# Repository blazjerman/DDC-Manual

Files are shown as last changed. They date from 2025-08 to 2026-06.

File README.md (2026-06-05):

# DDC Manual – Project Overview

A web-based manual and documentation page for my **Discrete Digital Clock (DDC)** project.

**Live Manual:** [blazjerman.github.io/DDC-Manual](https://blazjerman.github.io/DDC-Manual/)

---

## About This Page

This page serves as the official manual and visual guide for the DDC — a custom-built discrete digital clock. The DDC Manual provides technical details, images, and schematics related to the project.

Here you can:
- Learn about the DDC’s design and functionality.
- Explore internal schematics and how the circuit is wired.
- View photos of the final physical build.
- Understand the layout and structure of the renderer.
- Use the manual as a reference for your own builds or modifications.

---

## Repository Contents

This GitHub repository includes everything shown on the manual website:

- `/index.html` – The main landing page of the DDC Manual.
- `/files/` – Contains useful documentation and project files like:
  - `DDC_Schematic.pdf` – The complete schematic of the clock.
  - `DDC.3mf` – 3D file of clock.
- `/images/` – Contains pictures and renderings of the DDC project:
  - Photos of the assembled clock.
  - PCB layout screenshots.
  - 3D model renders of the design.

---

## Preview

Here’s a quick look at the 3D render of the DDC design:

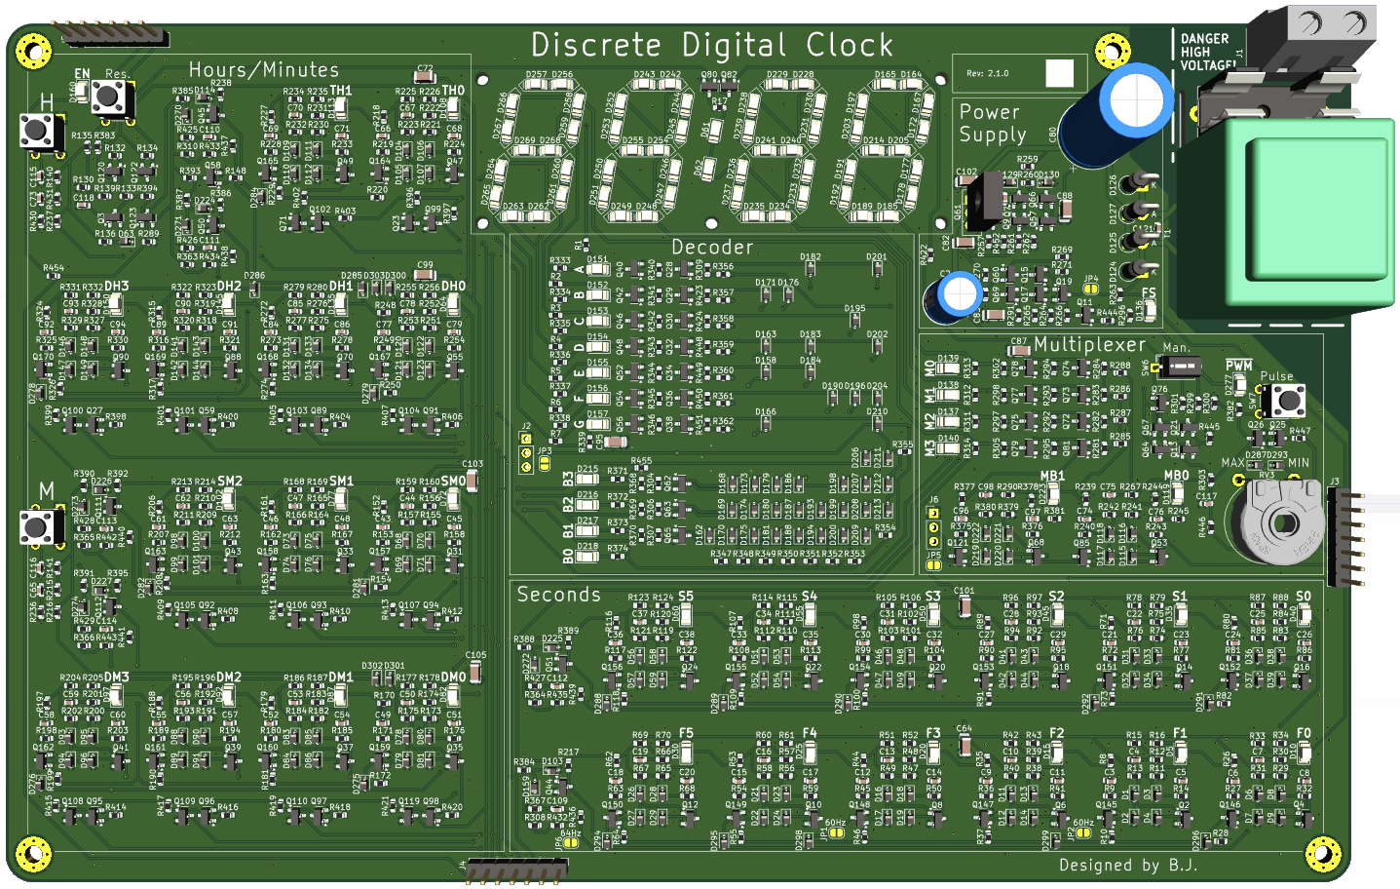
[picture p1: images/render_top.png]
DDC Render


> *Render of DDC*

---

## License

**DDC (Discrete Digital Clock) © 2025 Blaž Jerman**  
Licensed under [Creative Commons Attribution-NonCommercial 4.0 International (CC BY-NC 4.0)](https://creativecommons.org/licenses/by-nc/4.0/)

---

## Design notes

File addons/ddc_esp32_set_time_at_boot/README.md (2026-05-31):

# ESP32 WiFi Clock Setter

This ESP32 add-on sets the clock automatically when the clock boots.

On startup, the ESP32 connects to WiFi, gets the current time from NTP, turns WiFi off, and then uses the clock's J5 header to start and set the external clock.

## Installation

1. Install ESP32 board support in Arduino IDE:
   - Open **File -> Preferences**
   - Add this URL to **Additional Boards Manager URLs**:

     ```text
     https://raw.githubusercontent.com/espressif/arduino-esp32/gh-pages/package_esp32_index.json
     ```

   - Open **Tools -> Board -> Boards Manager**
   - Search for **esp32**
   - Install **esp32 by Espressif Systems**

2. Open the project file:

  ```text
  DDC-Manual/addons/ddc_esp32_set_time_at_boot/ddc_esp32_set_time_at_boot.ino
  ```

3. Set frequency:
  
  ```text
  Tools -> CPU Frequency -> 80MHz
  Tools -> Flash Frequency -> 40MHz
  ```

## ESP32 pins

| ESP32 pin | Use |
|---|---|
| GPIO 32 | Clock reset sense + clock start output |
| GPIO 27 | Set minutes output |
| GPIO 26 | Set hours output |
| GPIO 33 | WiFi reset button |
| GND | Common ground |

## Clock header J5

| J5 pin | Function | Connection |
|---|---|---|
| Pin 1 | Reset | Not used |
| Pin 2 | Boot reset check / start | ESP32 GPIO 32 |
| Pin 3 | 5V power | 5V supply only if safe |
| Pin 4 | Carry bit for day | Not used |
| Pin 5 | Set minutes | NPN transistor collector |
| Pin 6 | Set hours | NPN transistor collector |
| Pin 7 | Ground | ESP32 GND |

## Important power note

Do **not** power the ESP32 from USB and also connect another 5V supply to the ESP32 5V pin at the same time.

## J5 Pin 2 reset/start wire

Connect:

```text
J5 Pin 2 -> ESP32 GPIO 32
```

Behavior:

```text
Below 0.7V = clock reset/off
Above 0.7V = clock running
```

GPIO 32 is normally an analog input. At exact second `00`, ESP32 changes GPIO 32 to output HIGH to start the clock, then returns it to input mode.

## Minute and hour setting transistors

The hour and minute set pins are pulled up to **5V** on the clock board. The clock increments when these pins are pulled **LOW**, so they must be driven through an NPN transistor or another suitable level-shifting circuit. Do **not** connect these pins directly to the ESP32.

### Minutes

```text
ESP32 GPIO 27 -> 100k resistor -> NPN base
NPN emitter  -> GND
NPN collector -> J5 Pin 5
```

### Hours

```text
ESP32 GPIO 26 -> 100k resistor -> NPN base
NPN emitter  -> GND
NPN collector -> J5 Pin 6
```

Suitable NPN transistors:

```text
2N3904, BC547, 2N2222
```

## WiFi reset button

Connect:

```text
ESP32 GPIO 33 -> button -> GND
```

Hold the button while powering/resetting the ESP32. Keep holding for 3 seconds to clear saved WiFi and timezone.

## First WiFi setup

When no WiFi is saved, ESP32 creates:

```text
ESP32-WiFi-Setup
```

Connect to it and open:

```text
http://192.168.4.1
```

Enter WiFi SSID, password, and timezone. ESP32 saves them and restarts. You can check serial (bound rate 115200) for debugging.

## Startup sequence

1. ESP32 connects to saved WiFi.
2. It retries until WiFi works.
3. It retries NTP until time is known.
4. It turns WiFi off.
5. It checks GPIO 32 voltage.
6. If clock is reset/off, it waits for second `00`.
7. At exact `00`, GPIO 32 goes HIGH.
8. It pulses hours and minutes.
9. GPIO 32 returns to input mode.

## Troubleshooting

If WiFi setup opens every boot, check Serial Monitor (bound rate 115200) and GPIO 33 reset button wiring.
If hours/minutes do not increment, check NPN transistor wiring and common ground.

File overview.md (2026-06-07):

---
layout: page
title: Overview
permalink: /overview/
---

This section provides a simple explanation of how the clock operates. It is recommended for users who already have a basic understanding of electronics and some knowledge of transistors.

The clock includes many LED indicators to show how the system works (details about LED functions are provided below). The indicator LEDs operate at low current to increase their lifespan most run at 2 mA, except for the display LEDs, which are driven at around 15 mA due to multiplexing and their lower brightness.

All other components on the board are high quality. All ceramic capacitors are C0G type from Murata Electronics, and the transistors and diodes are sourced from ON Semiconductor.

The clock board is divided into different chambers, each labeled by name and representing a specific functional section. There are five labeled chambers:

- Power Supply  
- Seconds  
- Hours / Minutes  
- Decoder  
- Multiplexer  

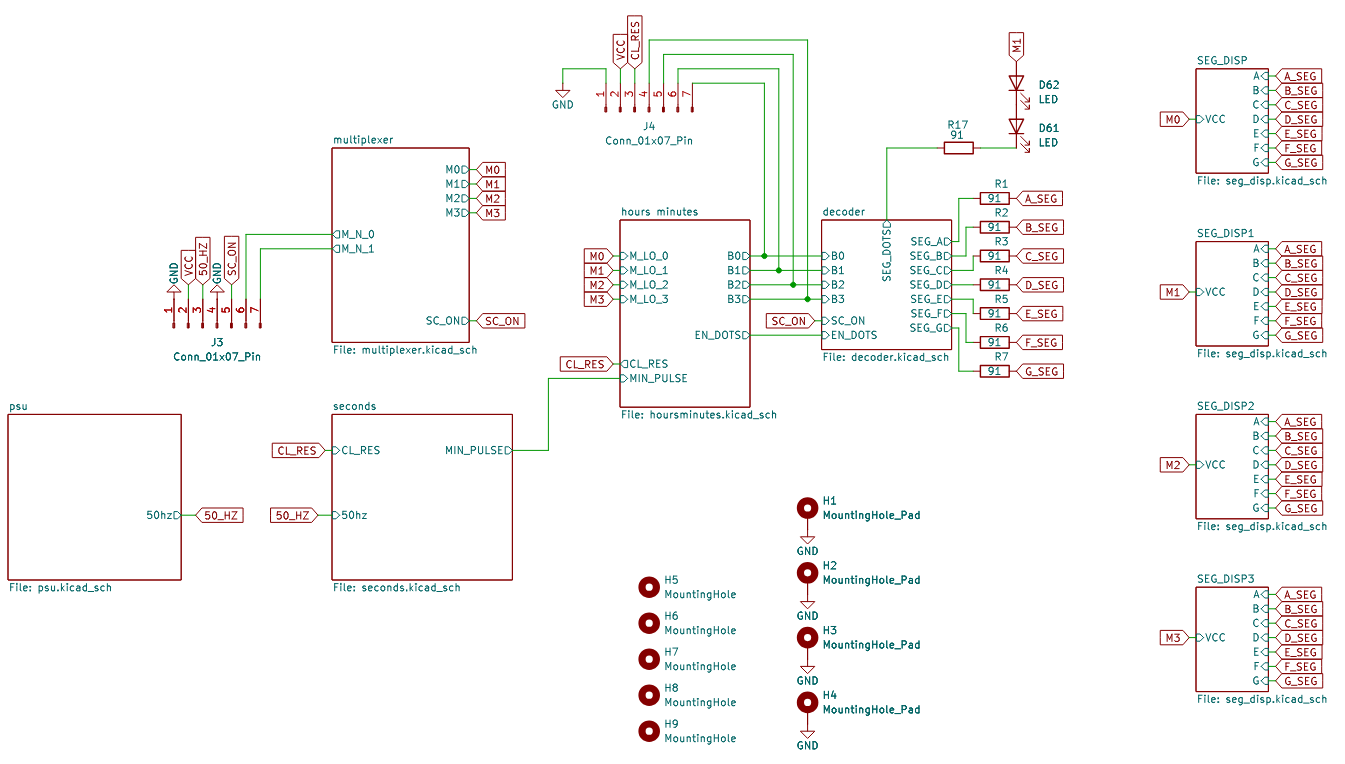
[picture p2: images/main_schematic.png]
Main schematic


You can find the full schematic of the clock here:  
[📄 View Clock Schematic (PDF)](/files/scheme.pdf)

Below is a simple description of each chamber.

### Power Supply

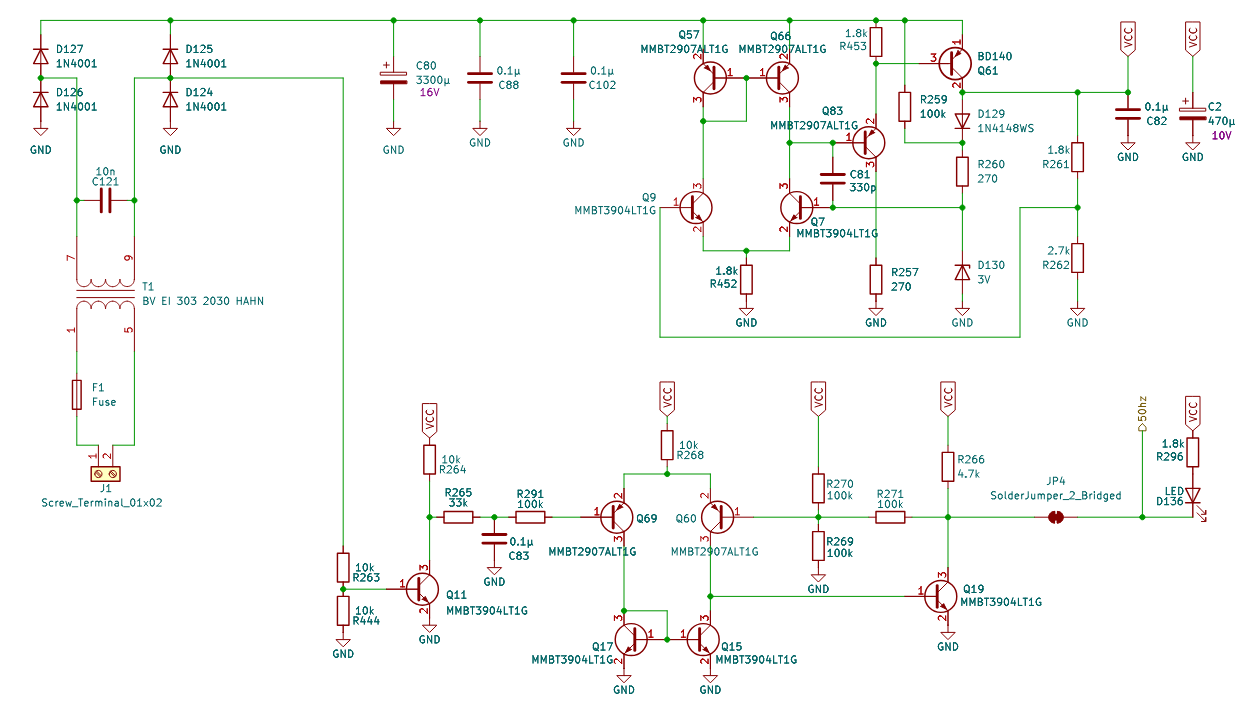
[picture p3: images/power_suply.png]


The power supply takes mains AC and converts it to a lower 6V using a transformer. A fuse is included on the primary side for safety. If a socket transformer is used, you should install a 1A fuse and short transformer pins 1 to 7 and 5 to 9. This allows you to connect the low voltage wires from the socket to the top right connector.

The transformer output is then rectified and regulated down to 5V using a low voltage drop down regulator. This regulator includes a comparator that compares a reference voltage from a 3V Zener diode to control the output. A BD140 transistor is used for voltage regulation. This transistor is rated to dissipate 1.25W without a heat sink; while a heat sink can be added, it is not required in this case.

On the bottom, there is a Schmitt trigger comparator that receives the mains frequency signal and filters out unwanted noise that may come from other devices on the same power network. There is also an LED indicator (marked "FS" frequency source on the board), which blinks at the mains frequency.

### Seconds

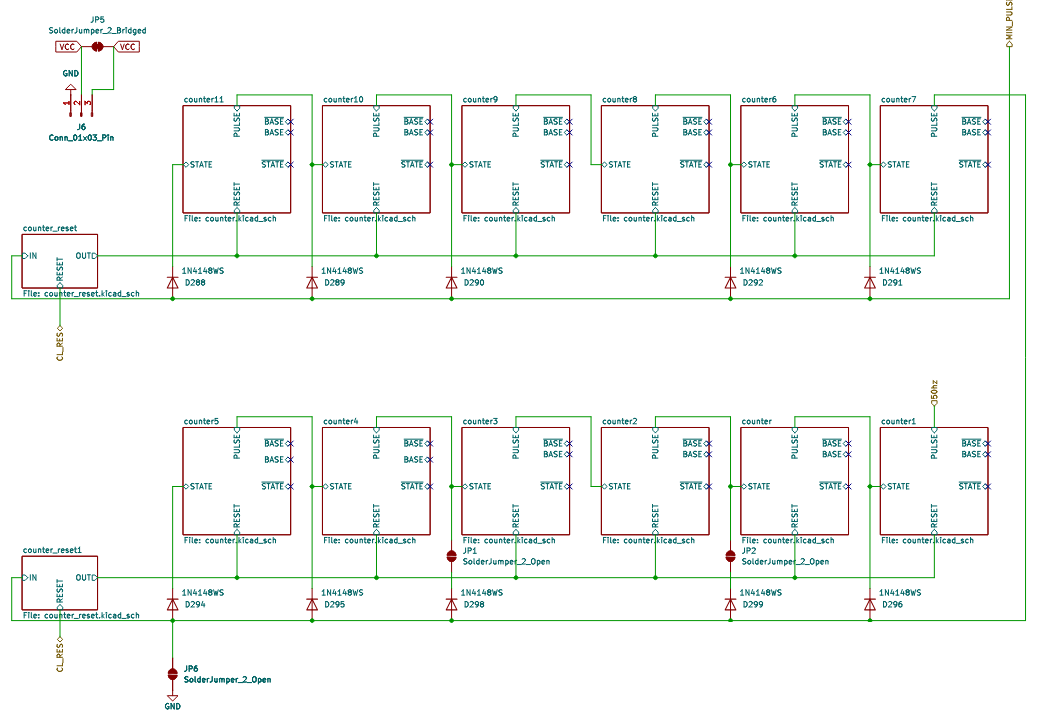
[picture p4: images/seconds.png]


This part of the clock converts the mains frequency into seconds, and then into minutes. It is made up of counters and reset counters.

Each counter is a toggle flip flop with two output states: a normal STATE and its negation. It has a RESET input, which sets it to its initial state when high, and a PULSE input, which toggles its state on the falling edge of the pulse.

The reset counter is a simple pulse extender that outputs high when the input is low. It also includes a reset input that forces the output high, allowing the clock to be reset.

The entire section consists of 12 counters and two reset counters. The first six counters, located at the bottom, convert the mains frequency into seconds. These counters are connected in series: the first receives a noise free mains frequency signal from the power supply at its pulse input; each of the remaining five counters is connected via the negated output of the previous counter to its own pulse input. Each counter also has an LED that lights up when its STATE output is high, allowing us to visually read the binary value. This design makes the clock digital, with each counter representing one bit of a binary number—in this case, a 6-bit number, with the least significant bit on the right (FS0) and the most significant on the left (FS5). The binary value can be easily converted to decimal by reading the LEDs.

A 6-bit counter can represent 64 values (0 to 63), but we need it to count only up to the mains frequency (e.g., 50Hz) in order to generate a 1-second pulse at the final counter. To achieve this, a reset counter resets the six counters once they reach a specific value. For example, if we want the counters to reset after 49 (binary 110001), we must detect that exact value and then pull all the reset inputs of the six counters high on the next cycle. The simplest way to detect this number is by using an AND logic gate on all the outputs that should be high before the reset point. This charges a capacitor that will pull the transistor base low and reset the counters. This outputs low whenever the value is not the target, and high only when the exact reset value is reached.

This reset method has a minor issue: due to transistor delays, the reset value might briefly appear for a few nanoseconds; the same goes for propagation delay. This is not visible to the naked eye but can be detected using a high speed camera. The main advantage of this design is that the same reset logic can be used for all counters that need to reset at a specific value.

The second group of six counters converts seconds into minutes. They function similarly to the first group but are fixed to reset after 59 (binary 111011). Technically, with a 50Hz mains frequency, all 12 counters could be linked and reset together at a count of 300. However, this would make it difficult to visually convert the binary seconds into decimal using the LEDs from S0 to S5.

### Hours / Minutes

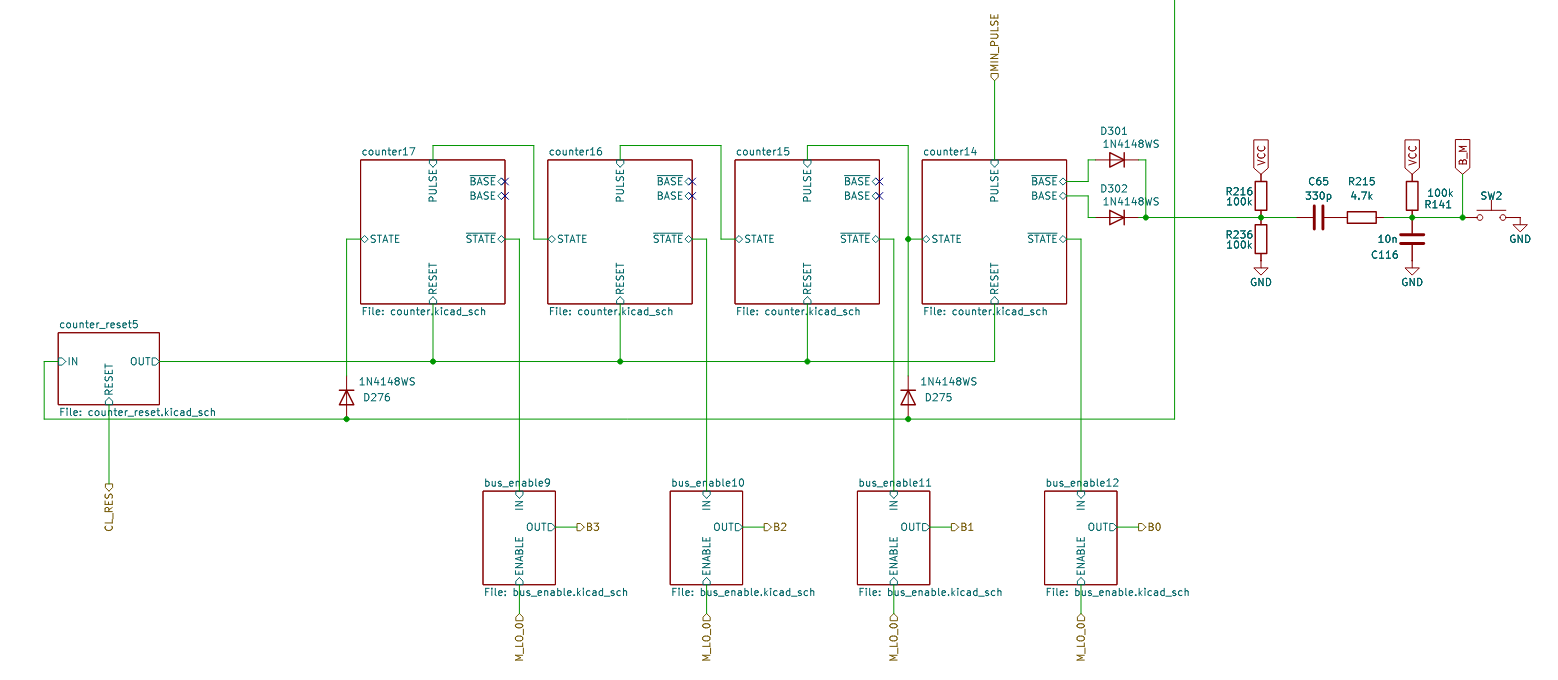
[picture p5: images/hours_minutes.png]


The hours and minutes parts of the clock work similarly to the second counters, using the same method for resetting. The 24-hour digit has additional logic for resetting, but it still follows the same style as the other counter resets. Additionally, there is a block of logic called bus_enable which, when ENABLE is high, connects IN to OUT. OUT is then connected to the correct bit in a 4-bit bus.

The bus is 4-bit and is used, with the help of a multiplexer and decoder, to convert each binary digit of the hours and minutes into decimal form for display. For simplicity, the bus uses an open drain approach.

There are also two increment counter logic circuits for setting the minutes and hours. They function in the same way as the counter PULSE.

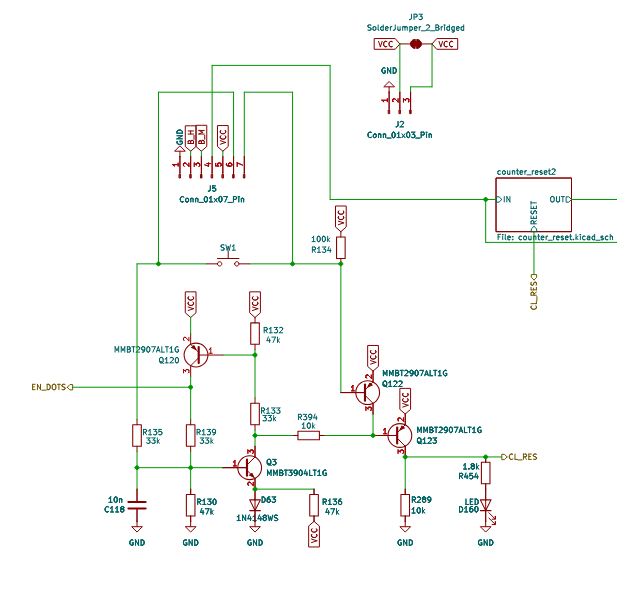
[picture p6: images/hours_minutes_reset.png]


This part of the circuit is responsible for resetting all the clock counters. It will also trigger a boot reset if the voltage drops too low for the clock to operate properly.

When the clock is powered on, the flip flop starts in the OFF state. It will remain OFF until the RESET button is pressed. Transistor Q122 ensures that once the button is pressed, the flip flop stays in the OFF state even if the button is not released immediately. This allows the clock to be precisely reset, setting all counters to 0.

LEDs act as dividers between numbers. They remain off when the clock is in a state that requires a boot reset.

### Decoder

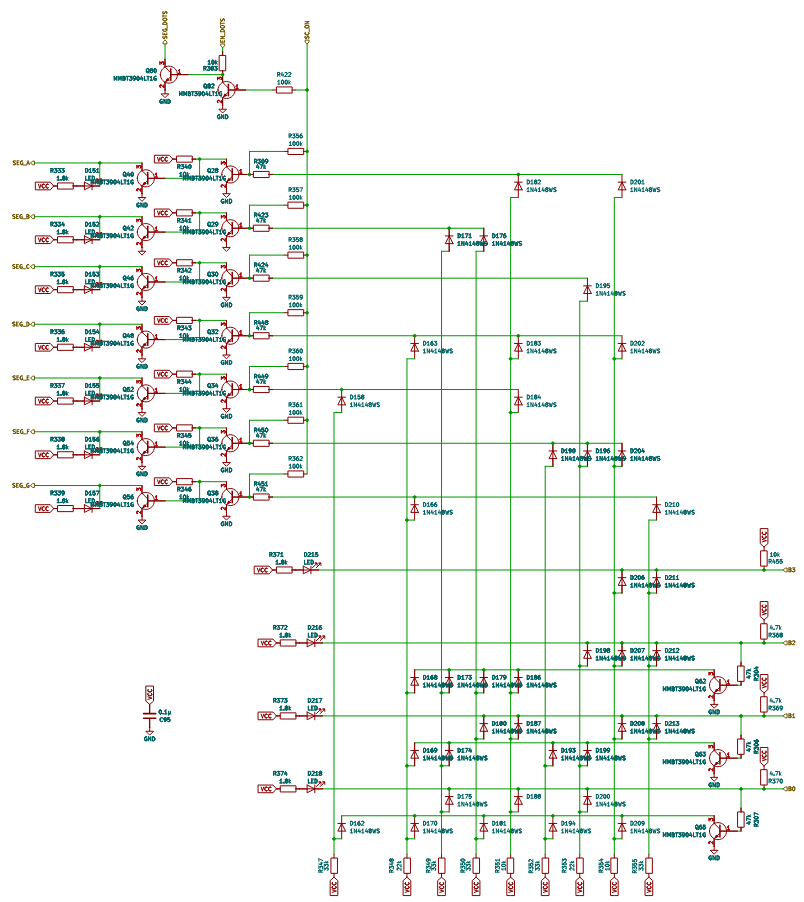
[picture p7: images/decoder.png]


The decoder’s purpose is to convert a binary number into the corresponding decimal digit and drive a 7-segment display accordingly. The binary input to the decoder is represented by LEDs labeled B0 to B3, which are connected to a 4-bit bus. The output can be seen on the display or on LEDs labeled A to G.

This decoder is similar in concept to a typical diode matrix found in other projects but is designed differently and optimized for space. The lower diode matrix receives a 4-bit bus input. Normally, this type of matrix converts binary input into all possible output states. For decimal display, 10 states (0 to 9) are required, with only one output line active (high) at any given time.

In standard designs, this output is usually inverted and passed to a second diode matrix to activate the correct segments of the display. In this design, inversion is not applied after the first matrix; instead, it is applied after the second diode matrix. This approach reduces both transistor and diode counts and avoids the voltage drop that would otherwise occur after the first matrix. The voltage drop is instead negated within the second matrix.

Due to this change, the second matrix is inverted first, allowing for further reduction in diode count. Additionally, a few diodes that are not essential for full 10-state decoding were omitted. With all these optimizations, the overall component count was reduced by approximately 50 elements.

Further simplification using transistor logic is possible, but this was avoided to maintain clarity and manageability of the design.

### Multiplexer

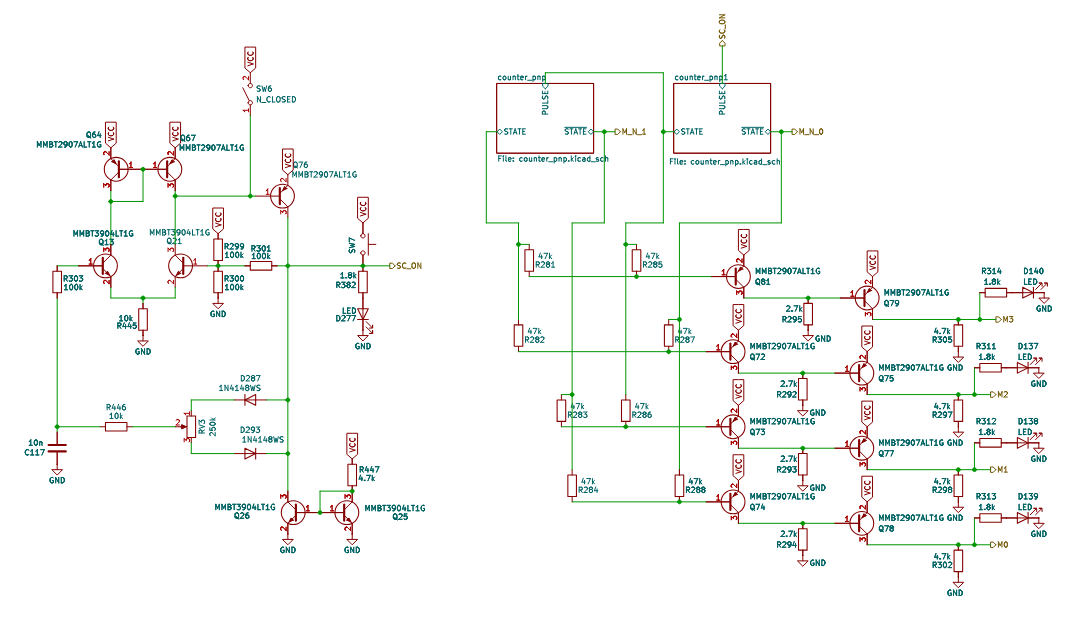
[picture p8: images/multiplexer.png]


The multiplexer controls which counter is connected to the decoder at any given moment, allowing the correct 7-segment display to be activated in a time-multiplexed manner. We have four 7-segment displays: two for hours and two for minutes. This means each display can be active for at most 1/4 of the time.

To cycle through the four display states, we can use a similar approach to the diode matrix used in the decoder, which involved two counters. However, due to the low number of states required, we can simplify this using just resistors.

A clock signal is also needed to drive the multiplexer. For this, we use a simple Schmitt trigger comparator with a charging/discharging capacitor oscillator that runs at approximately 1000 Hz. It includes a potentiometer to adjust the duty cycle (on/off ratio), which allows us to control the brightness of the digits. The duty cycle can be set anywhere from approximately 5% (dim) to 95% (bright).

A manual switch (SW6, labeled "MAN") is also included to disable the multiplexer clock. In this mode, a button labeled "PULSE" (SW7) allows manual advancement of the multiplexer for testing purposes. LEDs labeled M0 to M3 indicate the current selected state, with M0 representing decimal seconds and M3 representing the ternary hour.

This part is the biggest difference between this clock and other similar projects. Because of this, and the previously described optimizations, it uses significantly fewer components than the others.

### Additional Connections

This section provides a brief overview of the available expansion headers.
There are multiple headers reserved for connecting optional add-ons or custom modules.
Add-ons can be found in the [addons](https://github.com/blazjerman/DDC-Manual/tree/main/addons) folder.

Pin numbering ends at the ground pin. On all headers, the ground pin is marked with a square pad.

#### Top Header (J5 – 7 Pins)

- **Pins 1:** Reset. 
- **Pin 2:** Boot reset check/start. If the voltage is below 0.7V, it is in the boot reset state. To enable it, you can pull it high, and it will enable the clock and be above 0.7V.
- **Pin 3:** **Power (5 V)**.
- **Pin 4:** Carry bit for day.
- **Pin 5:** Set minutes.
- **Pin 6:** Set hours.
- **Pin 7:** **Ground**.

#### Middle Headers (J2/J6 – 3 Pins)

- **Pin 1:** **Power IN (5 V)**. (J2 for the Hours/Minutes, J6 for the seconds)
- **Pin 2:** **Power (5 V)**.
- **Pin 3:** **Ground**.

(Used for battery backup. Nearby jumpers need to be cut.)

#### Bottom Header (J4 – 7 Pins)

- **Pins 1–4:** A 4-bit bus, with the **least significant bit on the left**.  
- **Pin 5:** A **reset needed** signal, which goes high when the clock needs to be reset.  
- **Pin 6:** **Power (5 V)**.  
- **Pin 7:** **Ground**.

#### Right Header (J3 – 7 Pins)

- **Pins 1–2:** A 2-bit binary value representing the current multiplexer state (i.e., which digit is selected).
- **Pin 3:** Multiplexer pulse. If manual mode is enabled, it can be controlled externally by pulling it high for the off state and low for the high state.
- **Pin 4:** **Ground**.
- **Pin 5:** Mains frequency from comparator.
- **Pin 6:** **Power (5 V)**.
- **Pin 7:** **Ground**.

### Board and components

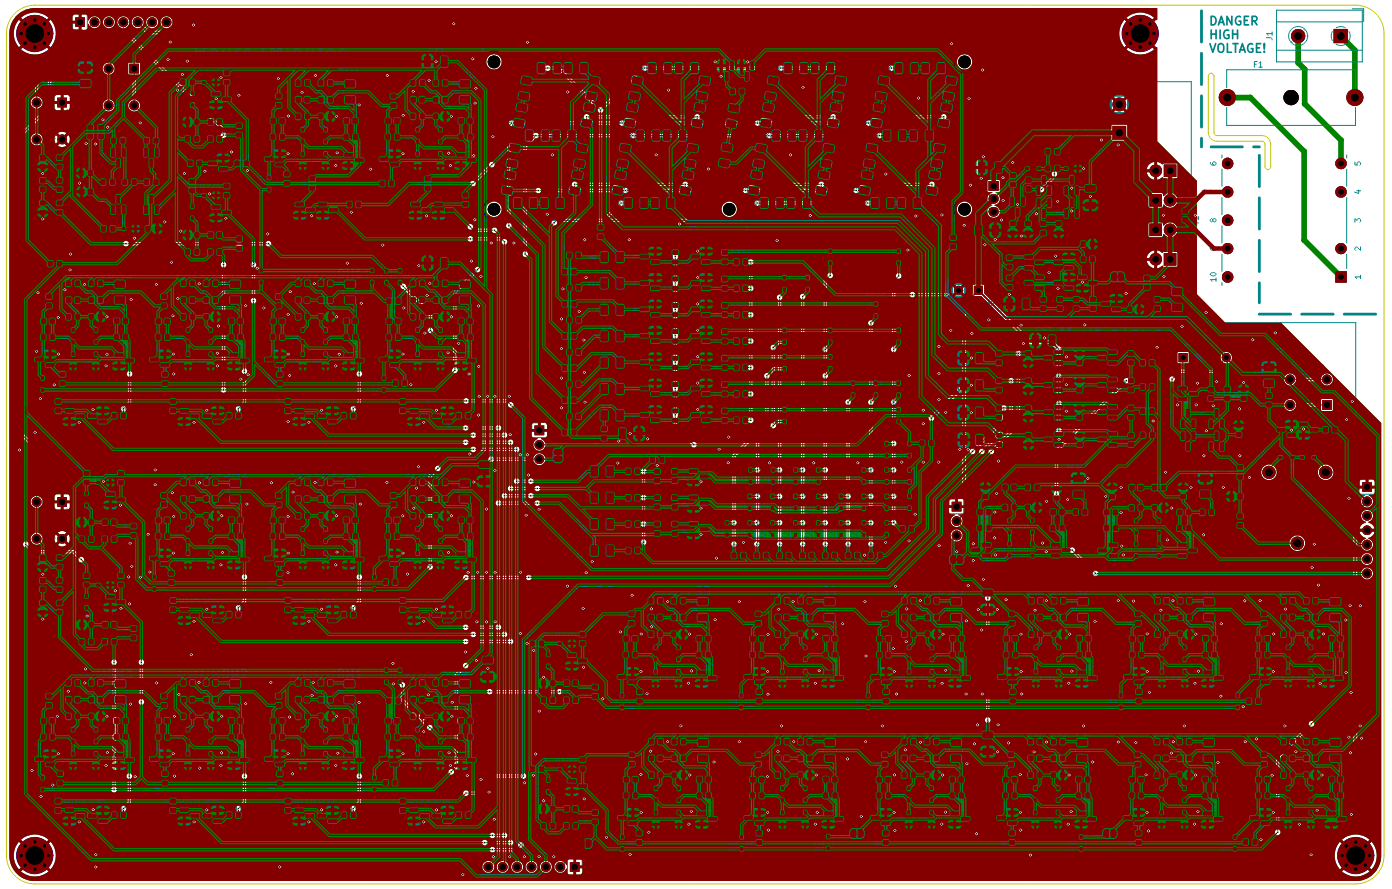
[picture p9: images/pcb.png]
Clock Render
  
*PCB*

[View 3D model online](https://3dviewer.net/#model=https://raw.githubusercontent.com/blazjerman/DDC-Manual/main/files/DDC.3mf)

The PCB is green, two layered, and 1.6 mm thick. All components, including the board, are RoHS compliant and high quality. Both sides have a GND copper pour for shielding, except in high voltage areas.

#### Components List

| Part Type | Value | Company | Qty |
|---|---|---|-----|
| Capacitor_SMD | 330p | - | 84  |
| Capacitor_SMD | 10n | Murata Electronics | 11  |
| Capacitor_SMD | 0.1μ | Murata Electronics | 12  |
| Capacitor_THT | 470μ | - | 1 |
| Capacitor_THT | 3300μ | - | 1 |
| Diode_SMD | 3V | Onsemi | 1 |
| Resistor_SMD | 91 | - | 8 |
| Resistor_SMD | 270 | - | 2 |
| Resistor_SMD | 1.8k | - | 48  |
| Resistor_SMD | 2.7k | - | 5 |
| Resistor_SMD | 4.7k | - | 98  |
| Resistor_SMD | 10k | - | 45  |
| Resistor_SMD | 22k | - | 2 |
| Resistor_SMD | 33k | - | 9 |
| Resistor_SMD | 47k | - | 106 |
| Resistor_SMD | 100k | - | 104 |
| Potentiometer_THT | 250k | Piher | 1 |
| Diode_THT | 1N4001 | - | 4 |
| Diode_SMD | 1N4148WS | - | 187 |
| Transistor_THT | BD140 | - | 1 |
| Transformer_THT | BV EI 303 2030 HAHN| HAHN | 1 |
| Connector_PinHeader | Conn_01x03_Pin | - | 2 |
| Connector_PinHeader | Conn_01x07_Pin | - | 3 |
| Fuse | Fuse | Schurter | 1 |
| LED_SMD | LED | LiteOn | 103 |
| Transistor_SMD | MMBT2907ALT1G | Onsemi | 23  |
| Transistor_SMD | MMBT3904LT1G | Onsemi | 113 |
| Button_Switch_THT | N_CLOSED | - | 1 |
| Screw_Terminal | Screw_Terminal_01x02 | | 1 |
| Button_Switch_THT | SW_Push | | 4 |

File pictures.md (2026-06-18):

---
layout: page
title: Gallery
permalink: /pictures/
---

This page contains photos, oscilloscope screenshots, and short videos from the Discrete Digital Clock project.

### Finished clock

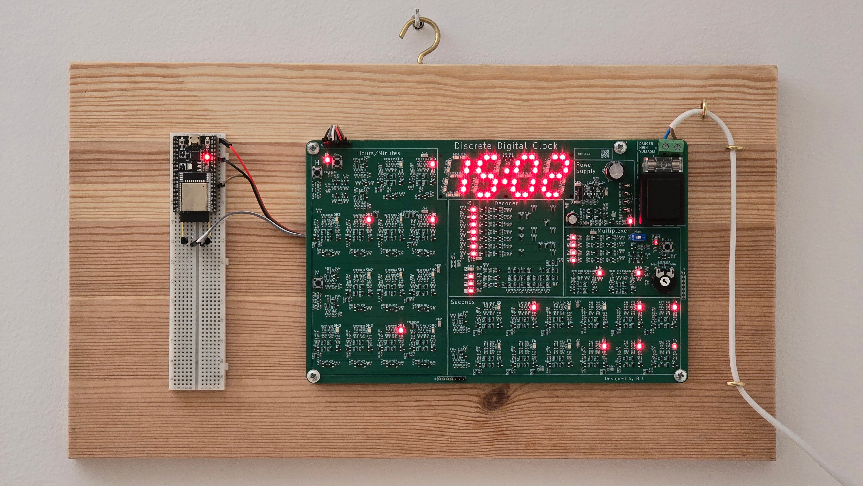
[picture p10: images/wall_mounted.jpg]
Wall mounted clock


The finished Discrete Digital Clock mounted on the wall.

---

### 50 Hz signal

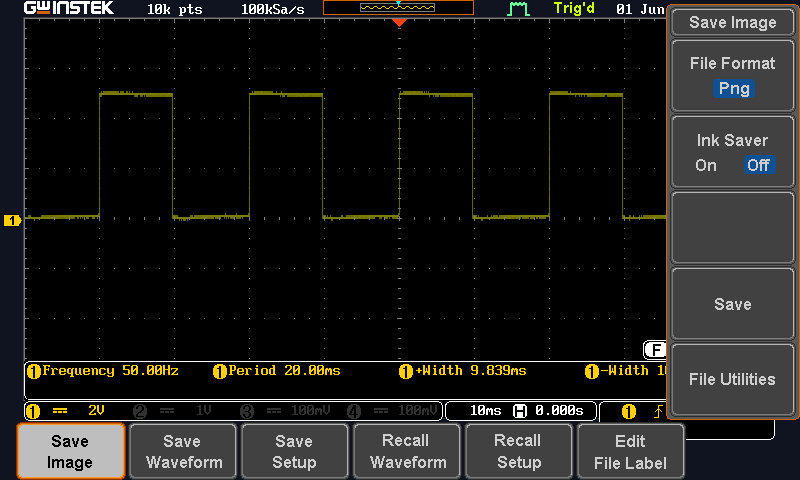
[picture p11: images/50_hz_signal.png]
50 Hz signal


Oscilloscope capture of the 50 Hz reference signal from power-line.

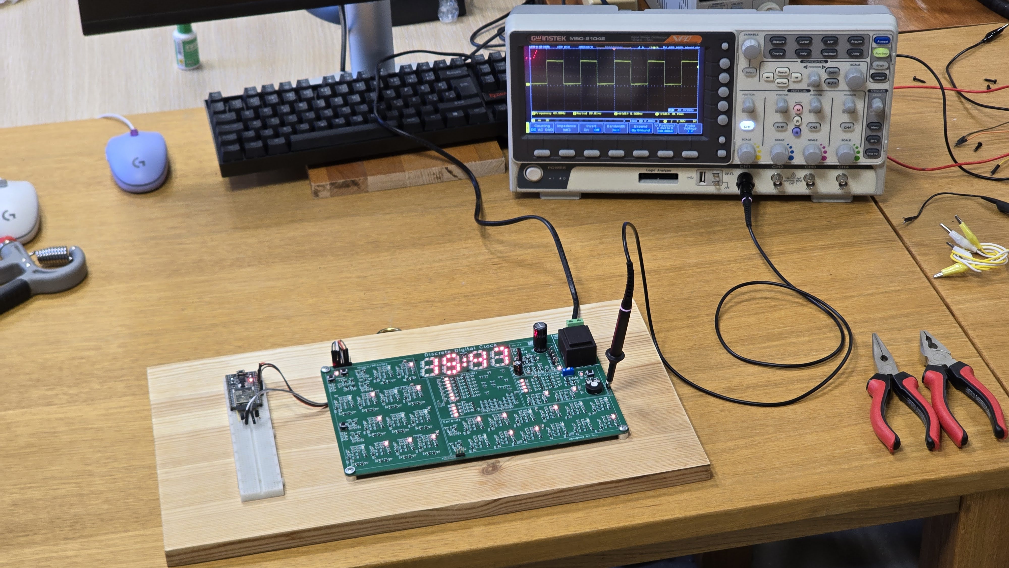
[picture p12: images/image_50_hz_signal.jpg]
50 Hz signal photo


Photo of the 50 Hz signal measurement during testing.

---

### PWM brightness control

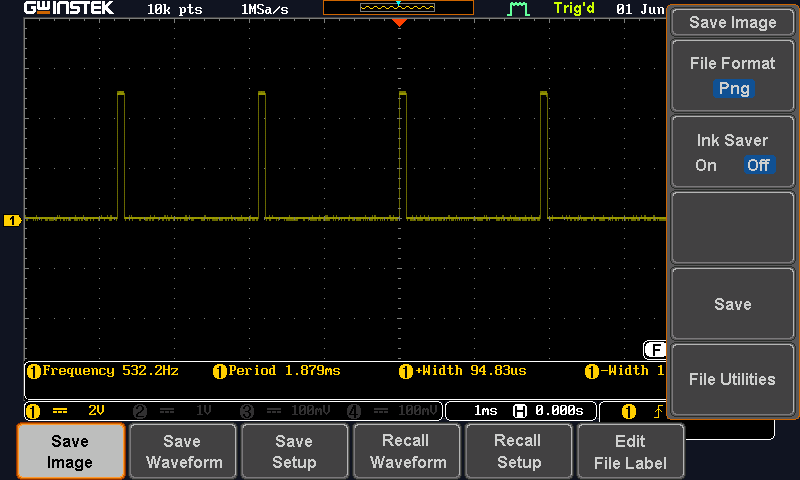
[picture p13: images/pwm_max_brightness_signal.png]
PWM maximum brightness signal


PWM signal when the display brightness is set to maximum.

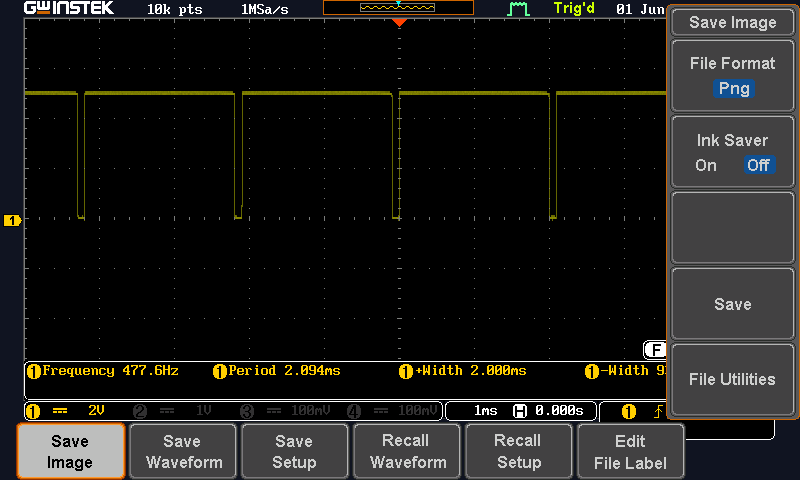
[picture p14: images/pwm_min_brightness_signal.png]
PWM minimum brightness signal


PWM signal when the display brightness is set to minimum.

---

### Multiplexer signal (max brightness)

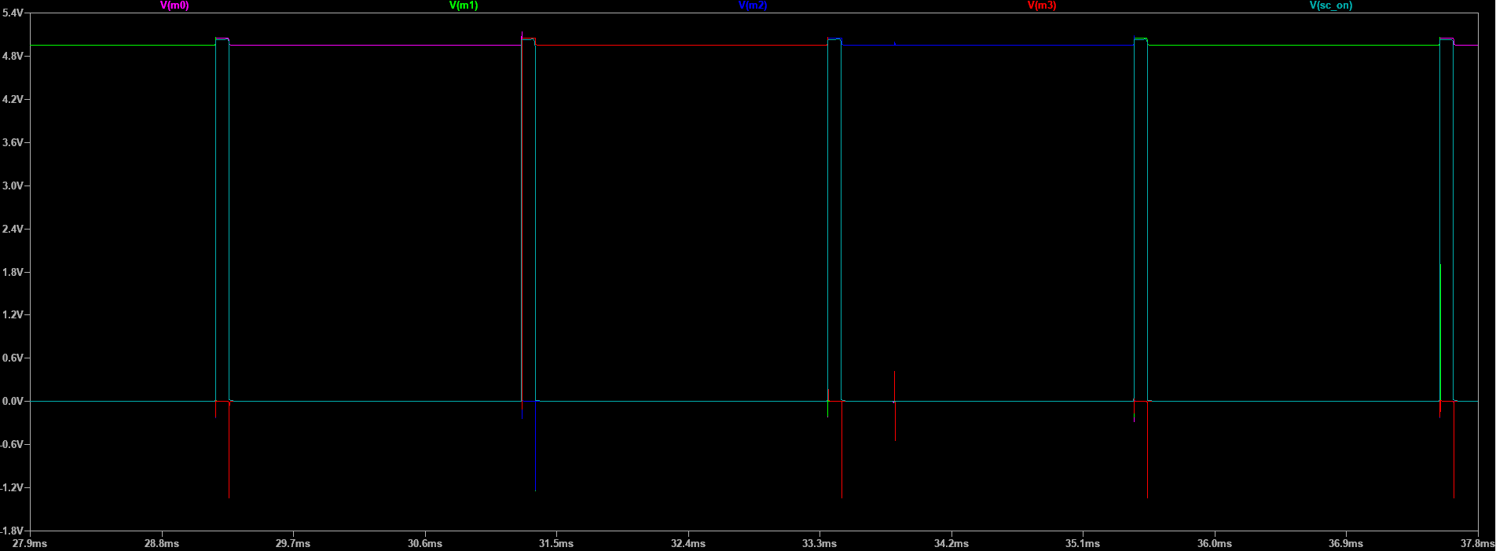
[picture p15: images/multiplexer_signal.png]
Multiplexer signal


LTspice capture of the multiplexing signal used to switch between the display digits. This was not measured on the real circuit because I did not have enough oscilloscope probes. In the real circuit, it behaves similarly, but with much smaller spikes due to wire resistance, capacitance and inductance.

Signals M0, M1, M2, and M3 act as the power or enable outputs for the individual display digits. The SC_ON (PWM) signal disables the currently active digit when it goes high and advances the multiplexer count. The next time SC_ON goes high, the next digit is enabled. During the disabled time, all transistors in the decoder and selector have enough time to settle and generate the correct signal before the next digit is turned on.
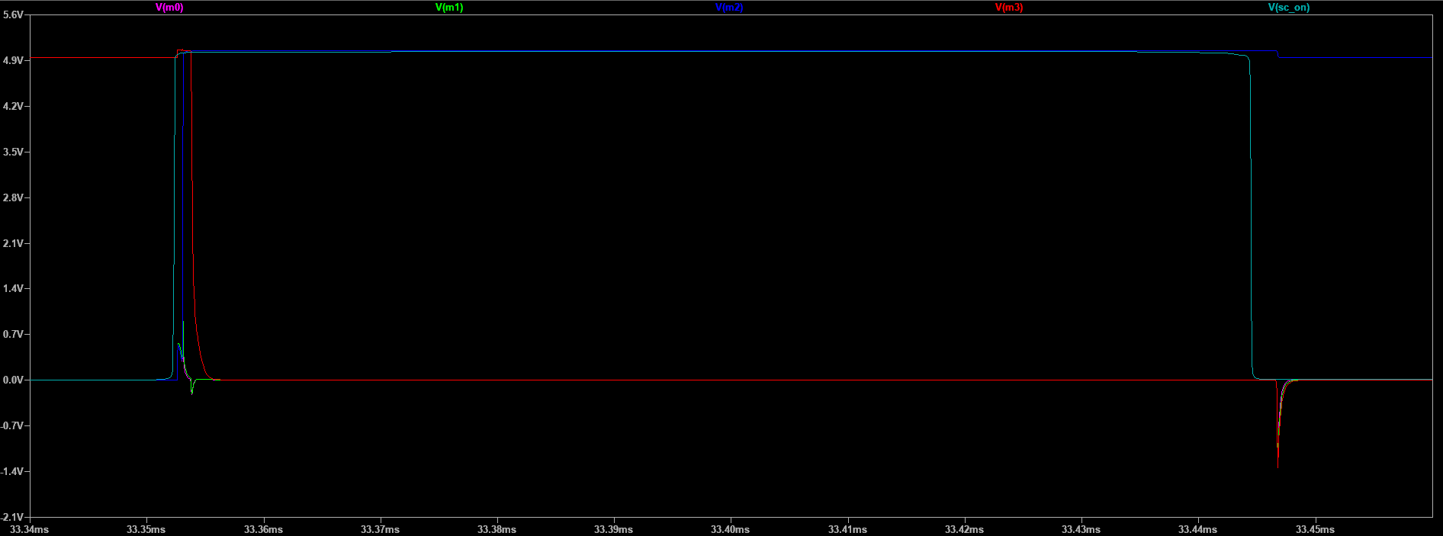
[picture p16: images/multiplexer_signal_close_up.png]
Multiplexer signal close up


Close-up view of the multiplexer signal where it swiches.

<video controls muted width="100%" preload="metadata">
  <source src="/DDC-Manual/images/multiplexing_additional_cap.mp4" type="video/mp4">
  Your browser does not support the video tag.
</video>

Video showing the effect of adding an additional capacitor to the multiplexing signal to increase the delay.

---

### Power supply ripple

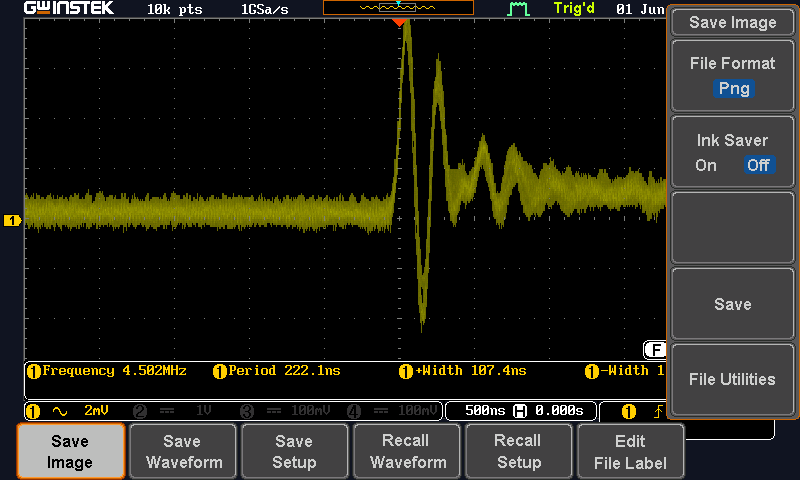
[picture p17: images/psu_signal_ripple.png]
Power supply ripple


Oscilloscope capture showing ripple on the linear drooper output during operation when all digits are 0. This little oscilation hapenes when miltiplexer swiches.

---

### Power supply Phase Margin

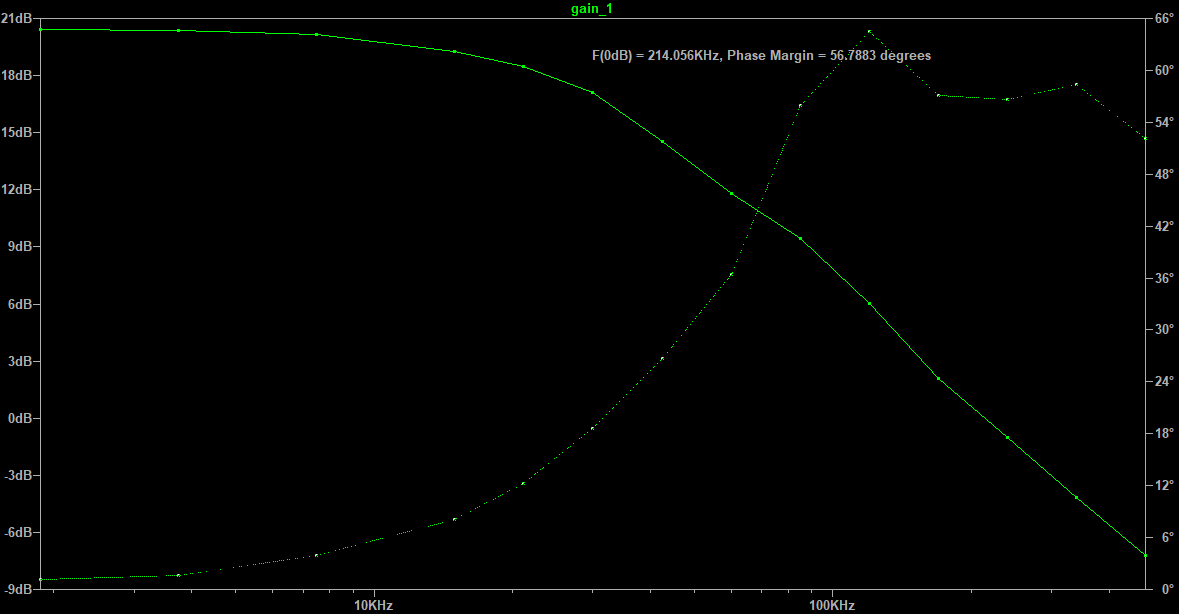
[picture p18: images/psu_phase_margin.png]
Phase margin diagram


The linear drooper has a simulated phase margin of about **56°** at **200 mA**. It was tested from **0 mA to 500 mA** and remained stable across the full load range. The low-frequency loop gain is around **20 dB**, which is modest compared with common regulator ICs, but this circuit achieves it with only **six transistors** while keeping the dropout voltage low.

---

### ESP32 Wi-Fi clock setter

<video controls muted width="100%" preload="metadata">
  <source src="/DDC-Manual/images/esp32_wifi_clock_setter.mp4" type="video/mp4">
  Your browser does not support the video tag.
</video>

This is ESP32 WiFi Clock Setter addon you can download code from [addons](https://github.com/blazjerman/DDC-Manual/tree/main/addons) folder. ESP32 sets the clock time when it boots by using the additional headers, which act like the hour and minute increment buttons.

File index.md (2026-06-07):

---
layout: home
title: Discrete Digital Clock Manual
---

Discrete Digital Clock PCB

## Introduction

This clock is an enlarged version of a logic IC, designed entirely from discrete components. It’s a fascinating way to see what’s inside a typical clock counter IC. The design is optimized for discrete components and simplified to use a relatively small number of parts.

The clock has four 7-segment displays that show a 24-hour time format with minutes. It also includes indicator LEDs for all counters, allowing you to see the binary values of hours, minutes, and seconds.

What makes this clock especially interesting is that it uses only basic components transistors, resistors, diodes, and LEDs. No microcontrollers or integrated circuits are involved. In fact, this clock could have been built as early as 1970, using only the technology available at that time.

All components used are **high quality and RoHS-compliant**, ensuring safety and durability. The **expected lifetime is extremely long** for nearly all parts except for the electrolytic capacitors, which may eventually require replacement after many years. Fortunately, these are easy to identify and replace if needed.

Another major advantage of this design is **visibility**: thanks to the widespread use of LEDs throughout the circuit, problems are easy to spot and diagnose. If something fails, you can typically see exactly where the issue is and fix it quickly.

The clock is meant for people who are interested in electronics enthusiasts who don’t take ICs for granted. It’s also great for those learning electronics or anyone who simply likes how it looks.

This project started during the COVID lockdowns, when I had a lot of free time and decided to design my own transistor based clock. That first version worked poorly and wasn’t very reliable. A couple of years later, I revisited the project and improved it significantly.

The clock’s precision depends on your local electric grid frequency, and is usually accurate to within ±20 seconds per year. Since it relies on mains frequency, it resets when the power goes out. This approach simplifies the design and reduces the component count. The fewer the components, the fewer things that can fail over time.

The clock is built on an 243 × 155 mm PCB that contains all necessary components. Surface mount (SMD) components are used to reduce soldering time and manufacturing cost. While it would definitely look cooler with through-hole (THT) parts, that would double the size and take much longer to assemble.

The default version supports 230V 50Hz input. There is also an option without a transformer, allowing you to solder your own for other voltages and frequencies (check the [Installation](#installation) section).  
If you're not comfortable working with mains voltage, you can use a socket transformer instead.

There are other similar digital clock kits online, often sold in THT form, but they aren’t optimized for discrete components. This design uses around 900 components, while others typically use between 1200 and 1800. Links to similar projects are provided at the end.

You can mount this clock on a wall using 3M screws, which can be attached to a wooden plate or other surface and then hung.

Clock Render  
*Rendered image of the Discrete Digital Clock*

For a more detailed preview of the clock internals, see the [Overview](overview.md).

---

## Installation

⚠️ Installation is straightforward, but **use caution**, especially when working with the mains-powered version. ⚠️

### 230V 50Hz Transformer Version

If you're using the mains powered version, you **must have a basic understanding of mains electricity**, as it can be **lethal**. It's essential to **isolate the mains section** of the clock (or the entire unit) to ensure safety. This version is intended for use in Europe and other regions that use 230V 50Hz power.

You will need to provide your own power cable. Connect the cable to the **top right side** of the clock, where the power supply connector is located.

This version of the clock consumes a maximum of 3W from the mains supply.

A **30 mA fuse** is included with the mains version for added protection.

---

### No Transformer Version

This version does not include a fuse or transformer, so you’ll need to purchase a PCB-mounted transformer separately, rated for your local voltage and frequency.  
If you're not comfortable working with high voltage, you can instead use a plug-in (socket) transformer.

The transformer must be rated for **6V AC** and capable of supplying at least **1.9VA**.  
It’s recommended to use a **60mA fuse on the primary side** for 110V, or a **1A fuse on the secondary side**.

You also need to bridge the bottom jumpers in the minutes section to set the frequency to 60 Hz.

---

### Size

The PCB measures **243 × 155 mm** and features **M3 mounting holes** for easy installation in enclosures or setups. It also includes holes for mounting a 3D printed segment cover or diffuser to improve display readability.

Below is a dimensioned drawing showing the main sizes of the PCB:

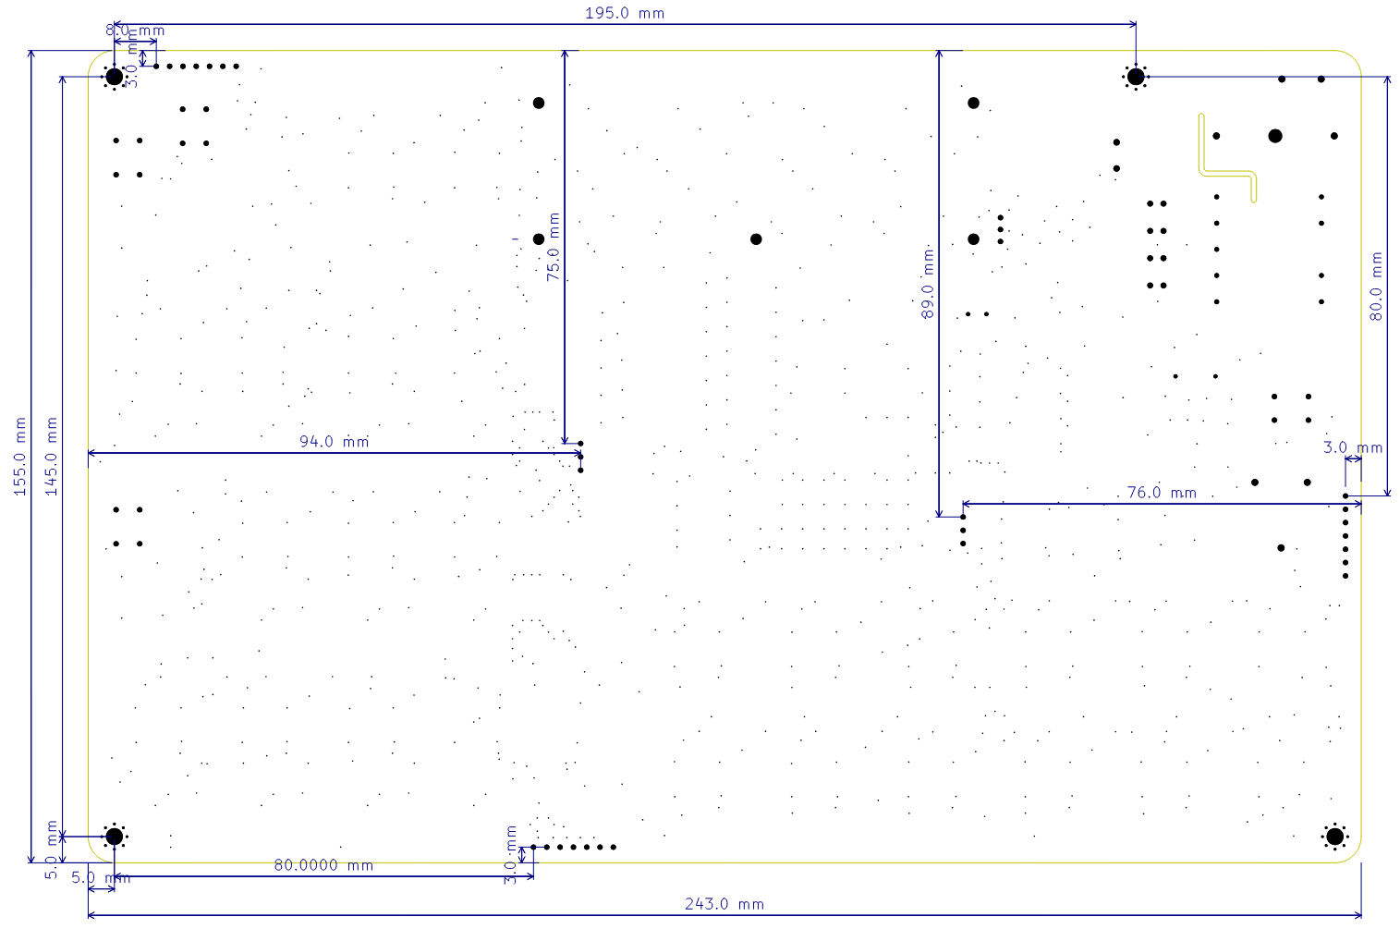
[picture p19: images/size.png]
Dimensioned Drawing of PCB


The 3D model of the clock case is available below. It can be opened in an online 3D viewer or downloaded from GitHub.

[View 3D model online](https://3dviewer.net/#model=https://raw.githubusercontent.com/blazjerman/DDC-Manual/main/files/DDC.3mf)  
[Download 3MF model](files/DDC.3mf)

---

## How to Use

When you power on the clock for the first time, it will be set to **00:00** without the colon (`:`) illuminated between the digits. All the counters will show zero and will not begin counting.

To activate the clock, you need to **press the Reset button**. This feature lets you know when a power outage has occurred, as the clock will remain at 00:00 until manually reset.

You can set the time using the following buttons:
- **M** (bottom left) to set **minutes**
- **H** (top left) to set **hours**

To set the seconds accurately, press the **Reset** button and release it **exactly at 0 seconds** (e.g., using another clock or stopwatch as reference).

Pin headers J5 can be used to attach an external MCU or similar device to set the clock automatically. (check Additional Connections in [Overview](overview.md))

---

## Connectivity / Add-ons

The clock has several connector pin headers. You can refer to the pinout diagram in the [Overview](overview.md) to identify each pin.

These connectors can be used to expand the clock’s functionality with features such as an alarm, day/date/year display, stopwatch, and more.

You can also connect the clock’s control pins to a microcontroller, such as an ESP32, so the clock can be automatically set every time it resets.

Add-ons can be found in the [addons](https://github.com/blazjerman/DDC-Manual/tree/main/addons) folder.

---

## Similar Discrete Clock Projects

There are several other discrete clock projects, but most of them use a different design philosophy. The DDC was designed to be compact, stable, self-contained, and practical, while still showing the internal logic of a clock built from individual components.

| Project | Approximate component count | Notes |
|---|---:|---|
| [KABtronics Transistor Clock](https://www.transistor-clock.com/) | 1247 discrete components | 194 transistors, 566 diodes, 400 resistors, 87 capacitors; large THT kit |
| [Mega Transistor Clock](https://mtc.mekweb.eu/) | 1630 parts | 596 diodes and 221 transistors; very large six-digit clock |
| [Techno Logic Art “The Clock”](https://techno-logic-art.com/clock.htm) | 1916 parts | Artistic 3D hand-soldered construction, not PCB based |
| [Transistor Logic Clock MkIII](https://transistorlogicclock.weebly.com/mkiii.html) | 1,440 discrete components | Very low-power transistor clock |
| [Ted Yapo’s Diode Clock](https://hackaday.io/project/11677-the-diode-clock) | 8000+ discrete components | Diode-diode logic clock, much larger and more complex |
| [Fernekes All Transistor Clock](https://www.fernekes.com/2020/04/all-transistor-clock/) | 600+ discrete components | Uses analog divider techniques and separate modules, more of an educational/art project |

The main difference is size and integration. The DDC is much more compact than most similar clocks, and all required components are on a single PCB, including the transformer, fuse, power supply, logic, display drivers, controls, reset circuit, indicator LEDs, and display. Because the clock uses SMD components, the board can be assembled by machine, so no manual soldering is needed for the main PCB. Even with SMD parts, it still looks visually interesting because the logic layout, indicator LEDs, and display remain visible. Many other projects are larger, use separate modules, require more wiring, or need a large amount of hand soldering.

Component count is also important. The DDC uses about 900 components, which is fewer than many similar clocks. Without indicator LEDs and overkill protection diodes, it has fewer than 700 components. The KABtronics clock has over 1,200 listed parts, Techno Logic Art’s clock has 1,916 parts, and Ted Yapo’s Diode Clock has more than 8,000 components.

The DDC uses SMD parts instead of through-hole parts. Through-hole parts are easier to see and look more “classic,” but they make the board much larger and require much more soldering. With SMD, the DDC can stay compact while still keeping the internal logic visible using indicator LEDs.

Stability is another major difference. The DDC is stable because of its onboard power supply circuit, compact SMD layout, and stronger binary reset logic. The shorter PCB traces made possible by SMD components reduce unwanted noise pickup, stray capacitance, and interference compared with larger through-hole layouts. The reset circuit is also more robust than simpler reset approaches used in some other discrete clocks, which helps the counters return reliably to the correct state.

The DDC can technically consume more power than very low power designs such as the Transistor Logic Clock MkIII, but most of that extra current is used by the indicator LEDs and the bright display. The indicator LEDs are driven at about 2 mA, and the 7-segment display segments are driven at about 15 mA. The logic itself consumes a similar amount of power to lower power transistor designs. Compared with very large discrete clocks, the DDC still needs only a fraction of the power.

The Fernekes All Transistor Clock is different from the others because it uses analog divider techniques. This makes it very interesting as an educational design, but it is not expected to be as reliable or stable as fully digital counter based clocks. Analog divider circuits depend more on component tolerances, adjustment, and drift, while digital binary counters are more predictable.

Overall, the DDC is not trying to be the largest, the most artistic, or the absolute lowest power discrete clock. It is designed as a balanced practical clock: compact, stable, self contained, bright, readable, easier to troubleshoot, and much smaller than most comparable fully discrete designs.

---

## More Photos and Videos

More photos and videos can be found in the [Gallery](pictures.md).

<script data-goatcounter="https://blaz.goatcounter.com/count" async src="//gc.zgo.at/count.js"></script>

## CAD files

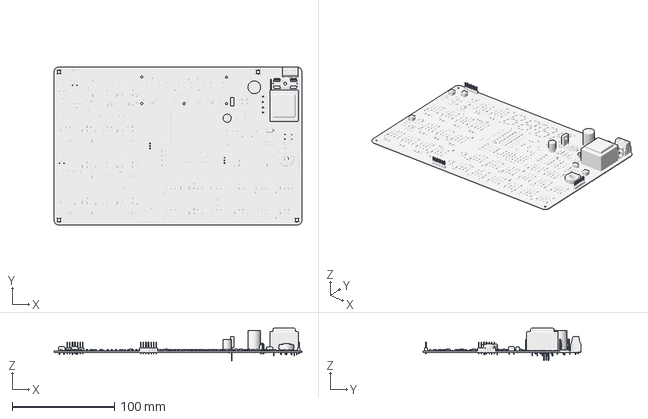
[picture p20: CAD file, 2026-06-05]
files/DDC.3mf
243.0 x 155.0 x 31.9 mm

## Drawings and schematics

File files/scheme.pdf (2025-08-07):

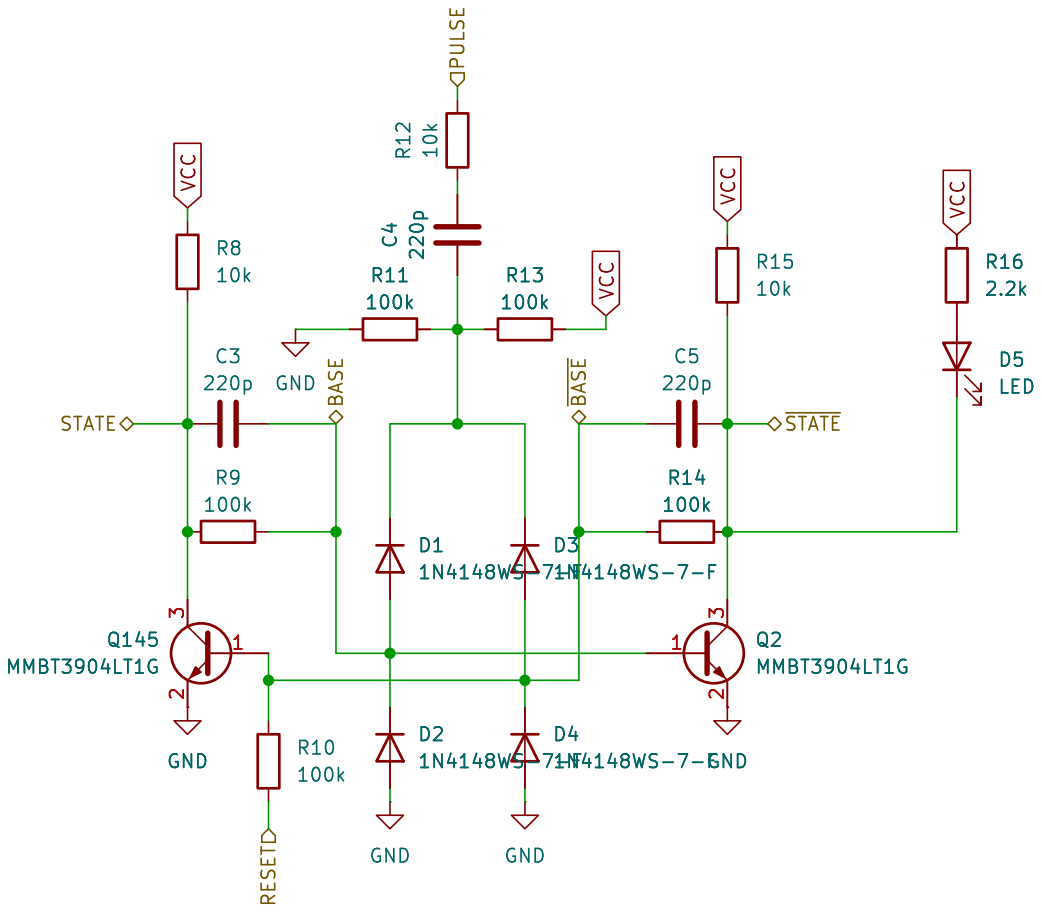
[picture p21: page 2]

Id: 2/52 Title: File: counter.kicad_sch Sheet: /seconds/counter/ R10

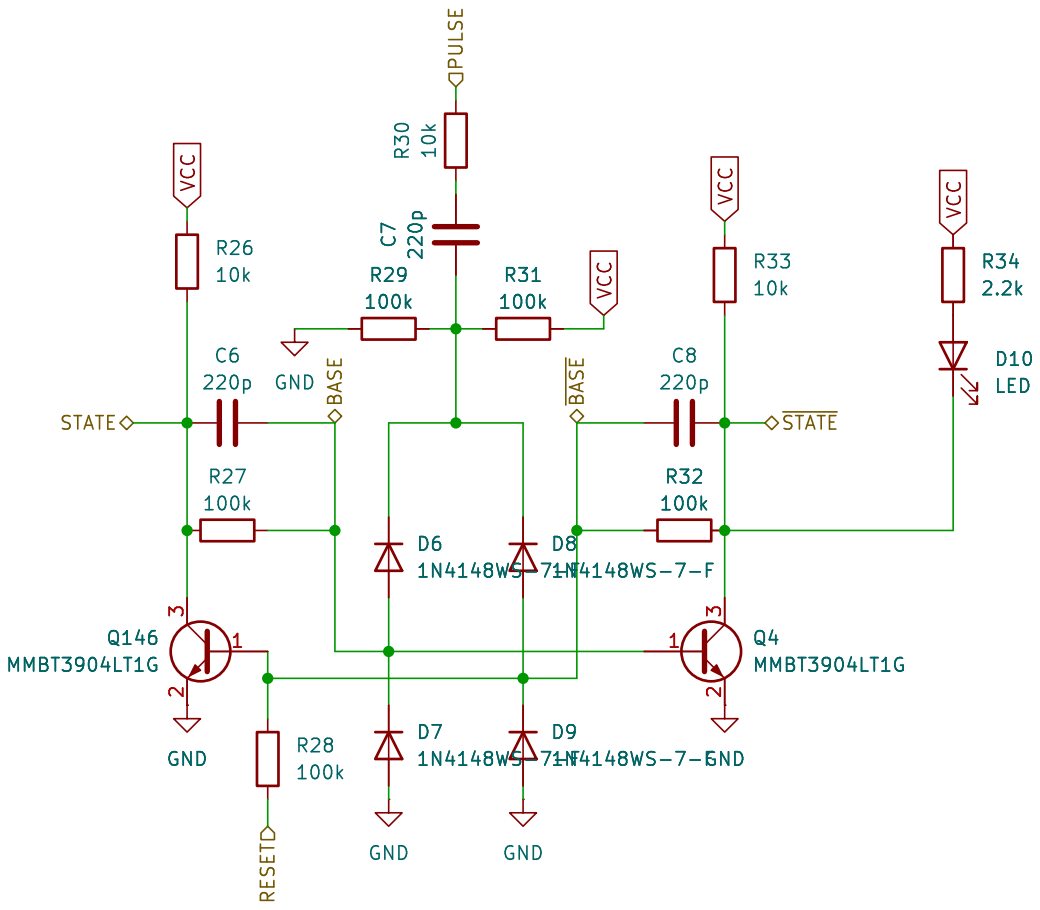
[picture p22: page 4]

Id: 4/52 Title: File: counter.kicad_sch Sheet: /seconds/counter1/ R28

Id: 5/52 Title: File: counter.kicad_sch Sheet: /seconds/counter2/ R36

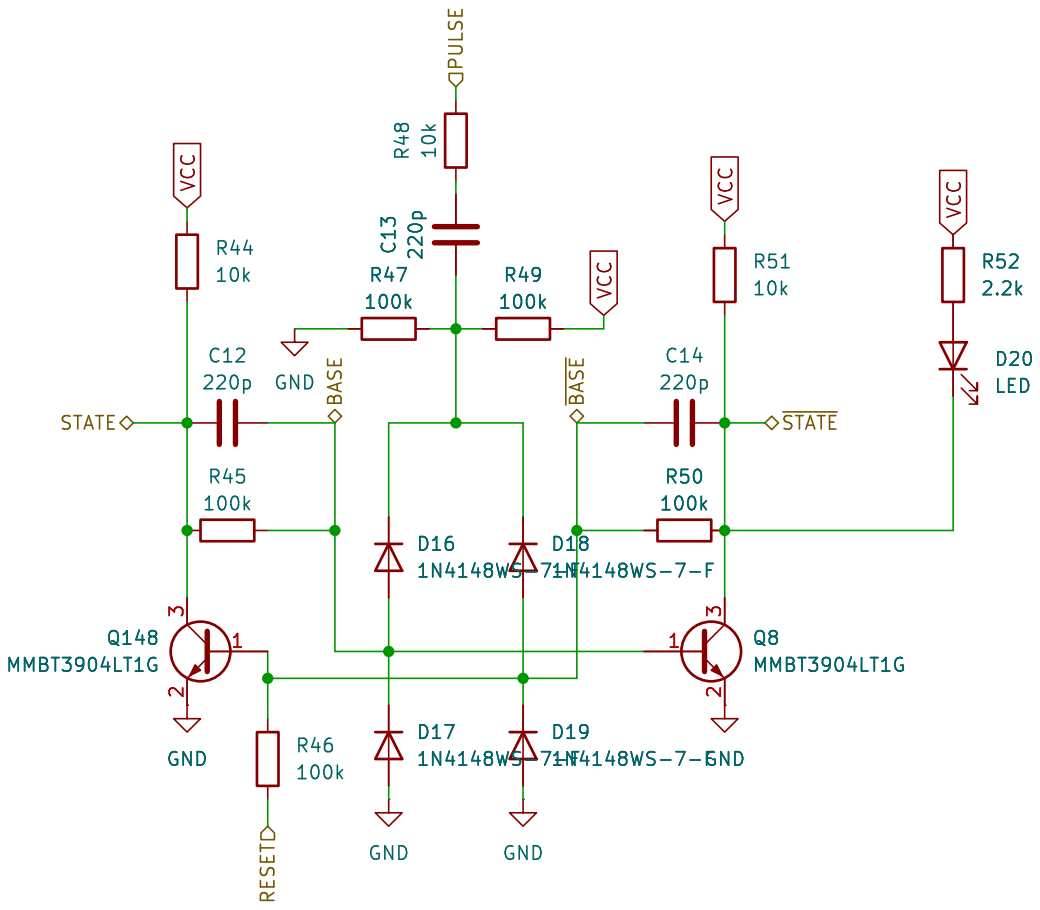
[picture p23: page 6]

Id: 6/52 Title: File: counter.kicad_sch Sheet: /seconds/counter3/ R45

Id: 7/52 Title: File: counter.kicad_sch Sheet: /seconds/counter4/ R54

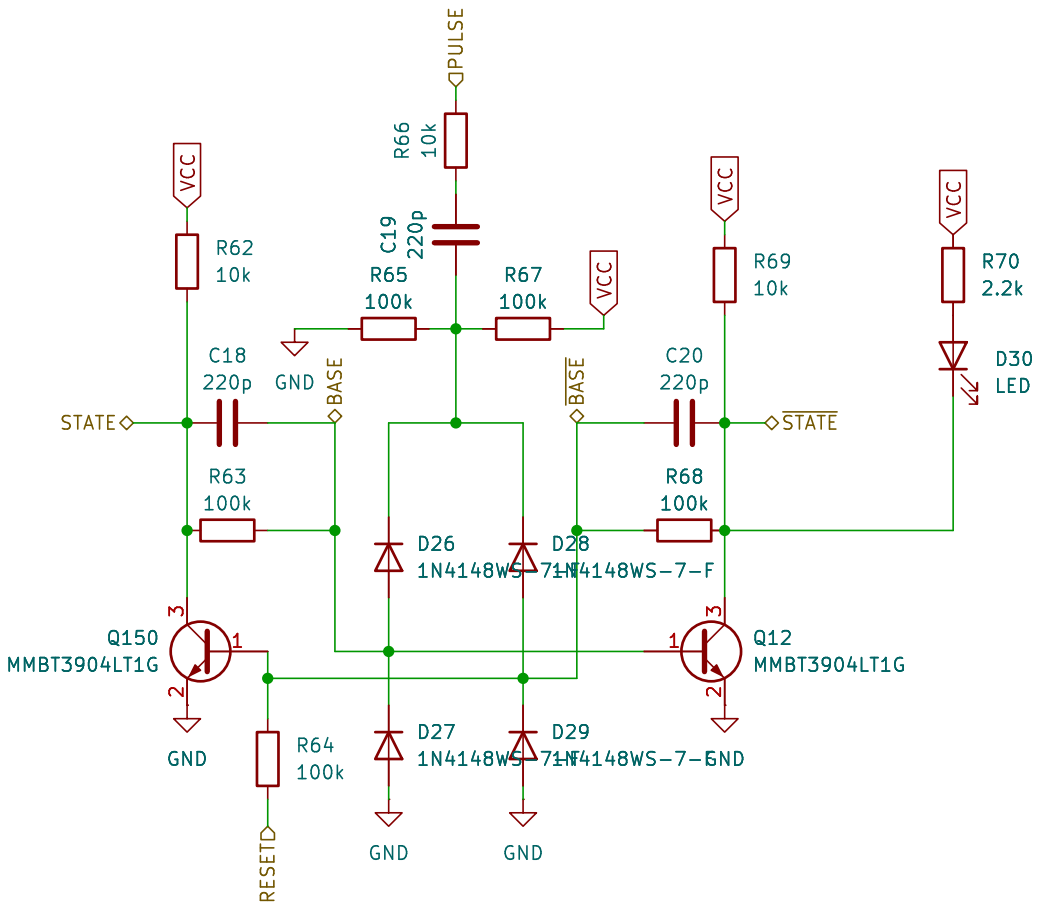
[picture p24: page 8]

Id: 8/52 Title: File: counter.kicad_sch Sheet: /seconds/counter5/ R63

Id: 9/52 Title: File: counter.kicad_sch Sheet: /seconds/counter6/ R72

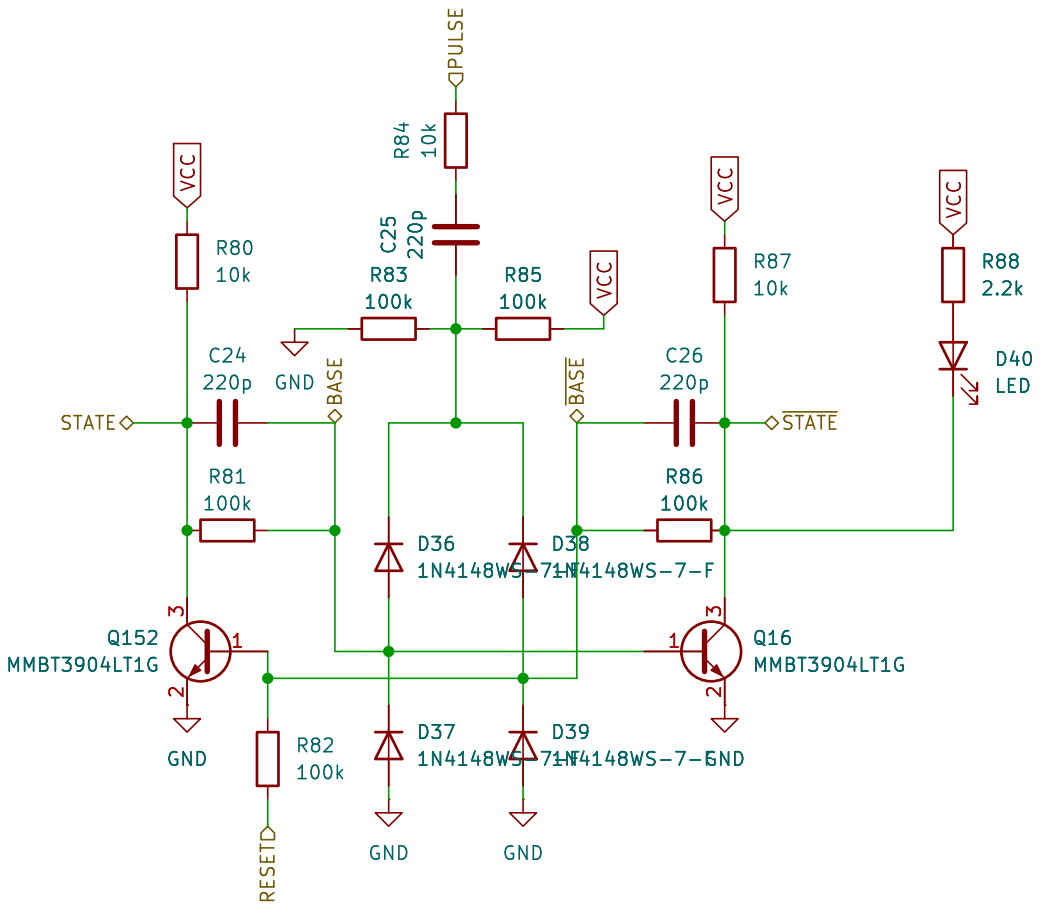
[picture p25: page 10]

Id: 10/52 Title: File: counter.kicad_sch Sheet: /seconds/counter7/ R81

Id: 11/52 Title: File: counter.kicad_sch Sheet: /seconds/counter8/ R90

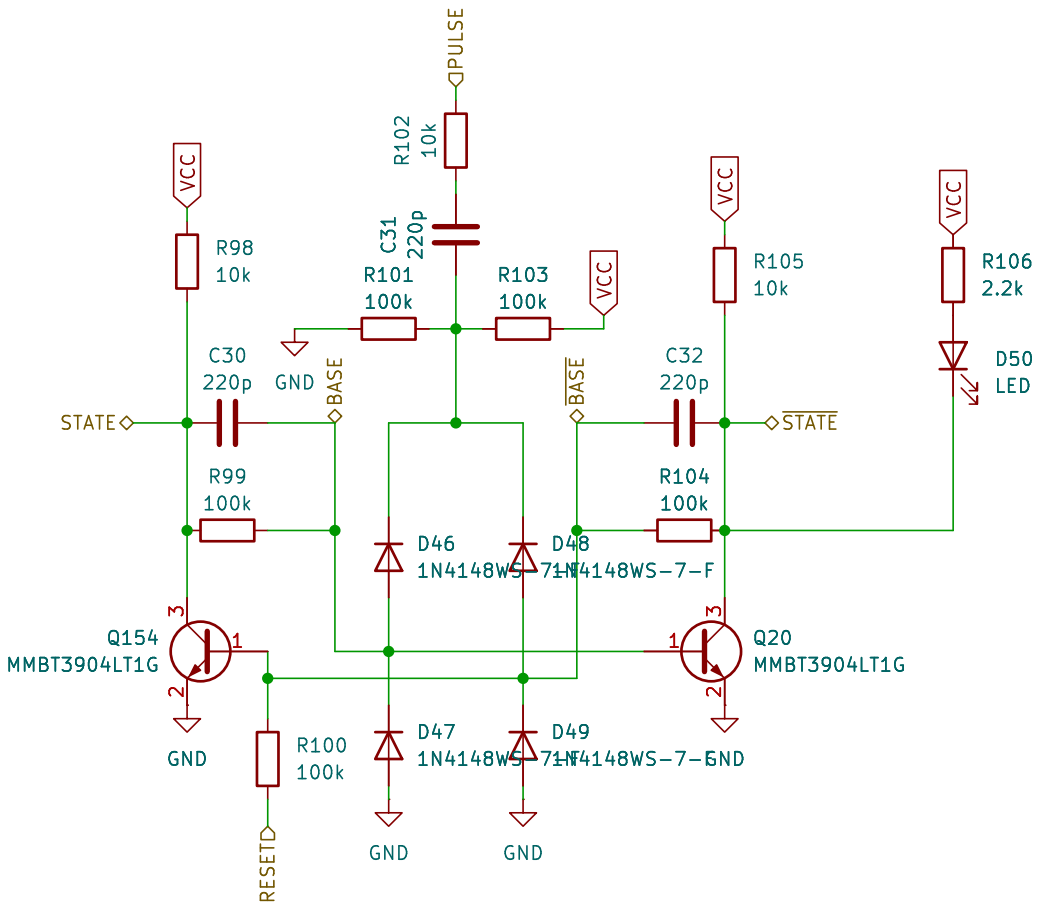
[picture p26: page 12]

Id: 12/52 Title: File: counter.kicad_sch Sheet: /seconds/counter9/ R99

Id: 13/52 Title: File: counter.kicad_sch Sheet: /seconds/counter10/ R108

Id: 14/52 Title: File: counter.kicad_sch Sheet: /seconds/counter11/ R117

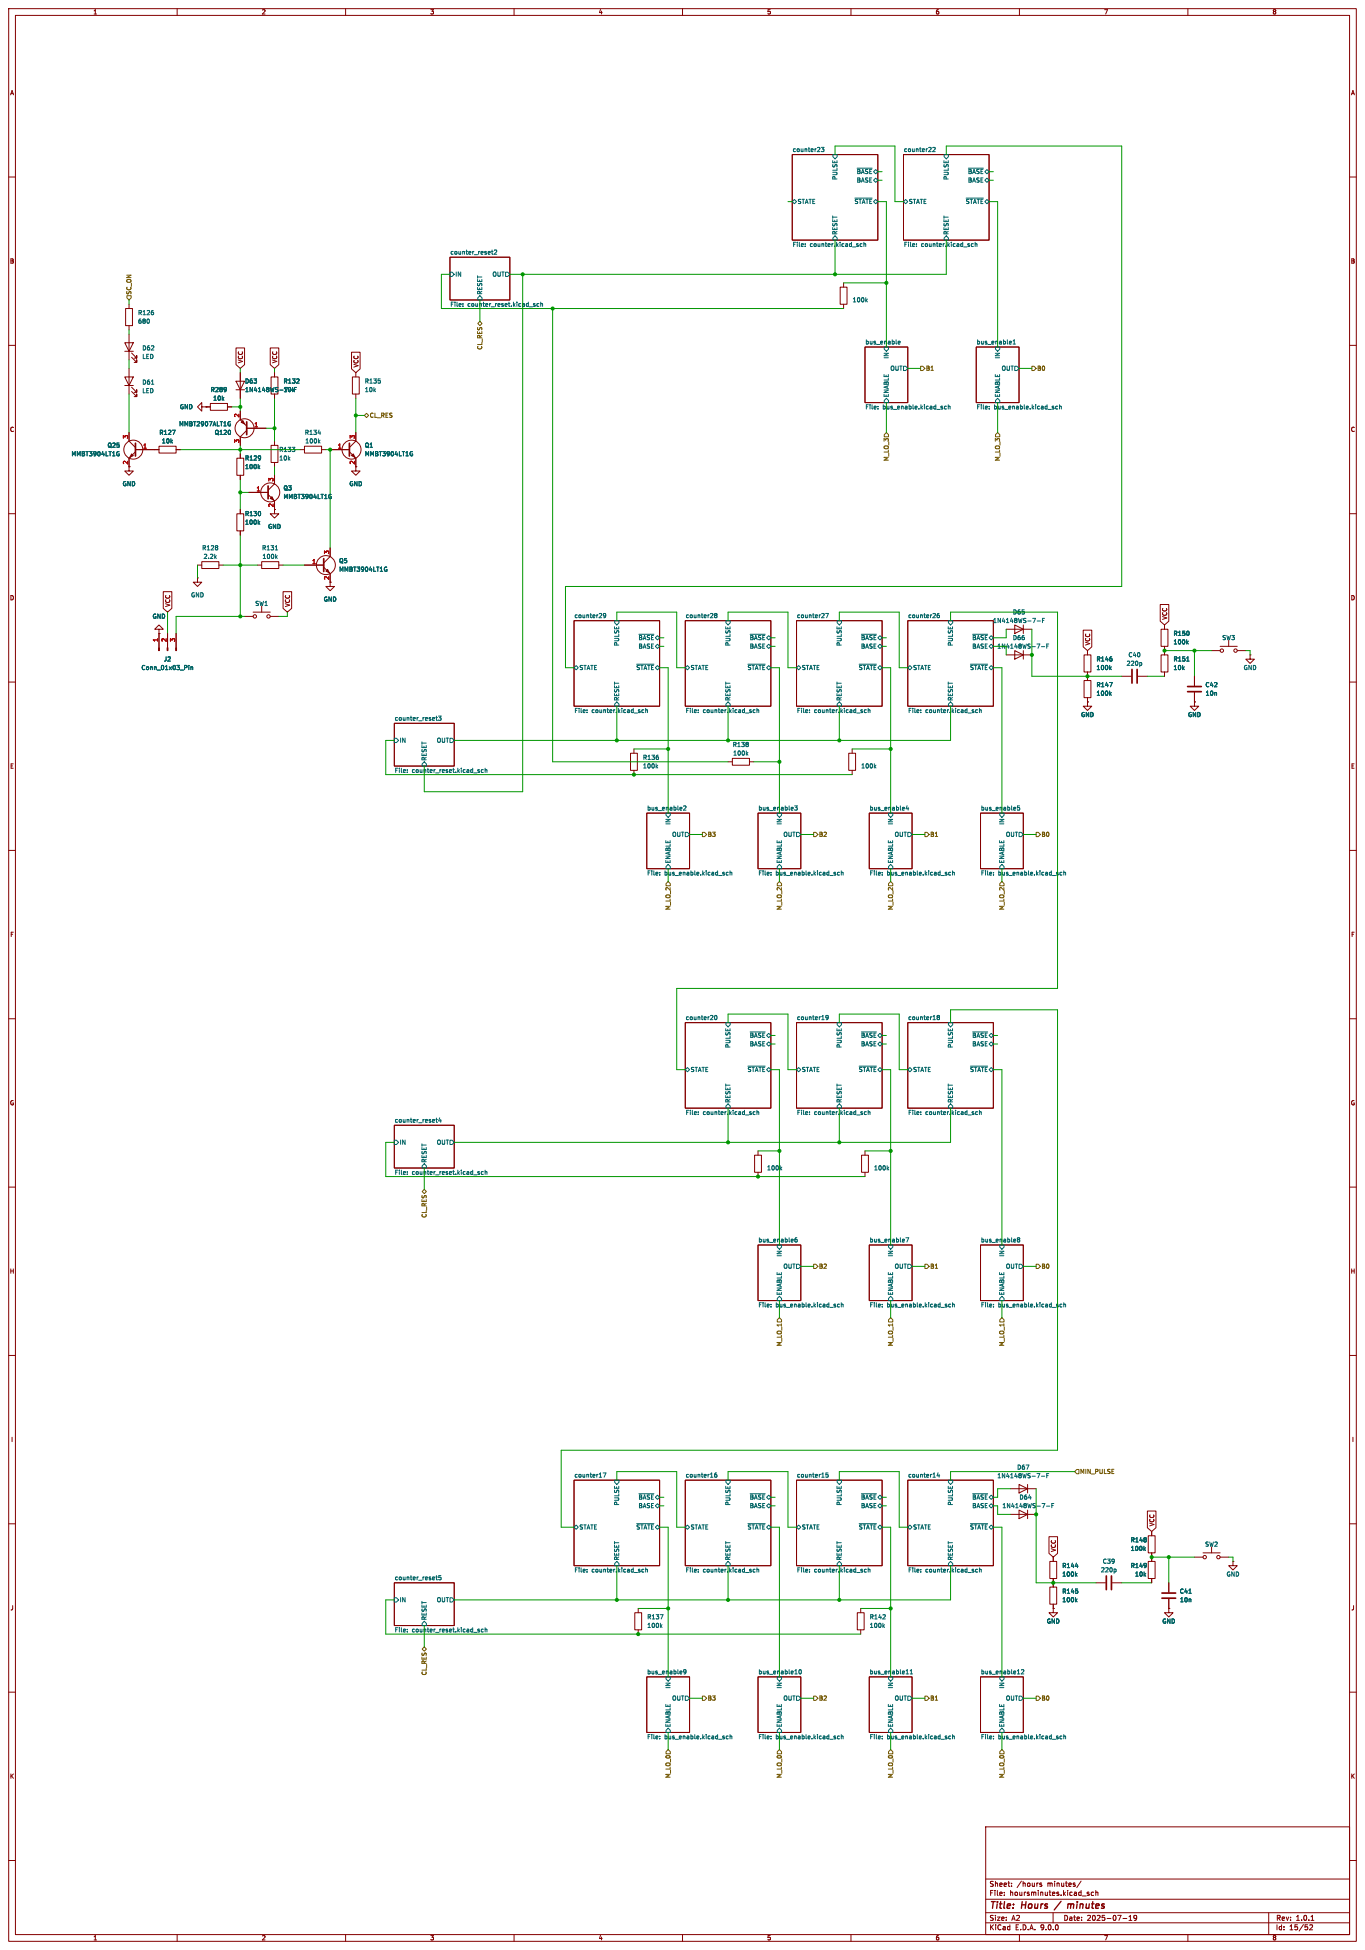
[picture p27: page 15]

bus_enable4 File: bus_enable.kicad_sch PULSE
bus_enable12 File: bus_enable.kicad_sch IN ENABLE OUT

bus_enable5 File: bus_enable.kicad_sch IN ENABLE OUT

counter18 File: counter.kicad_sch IN ENABLE OUT

counter14 File: counter.kicad_sch IN ENABLE OUT

Id: 15/52 Title: Hours / minutes

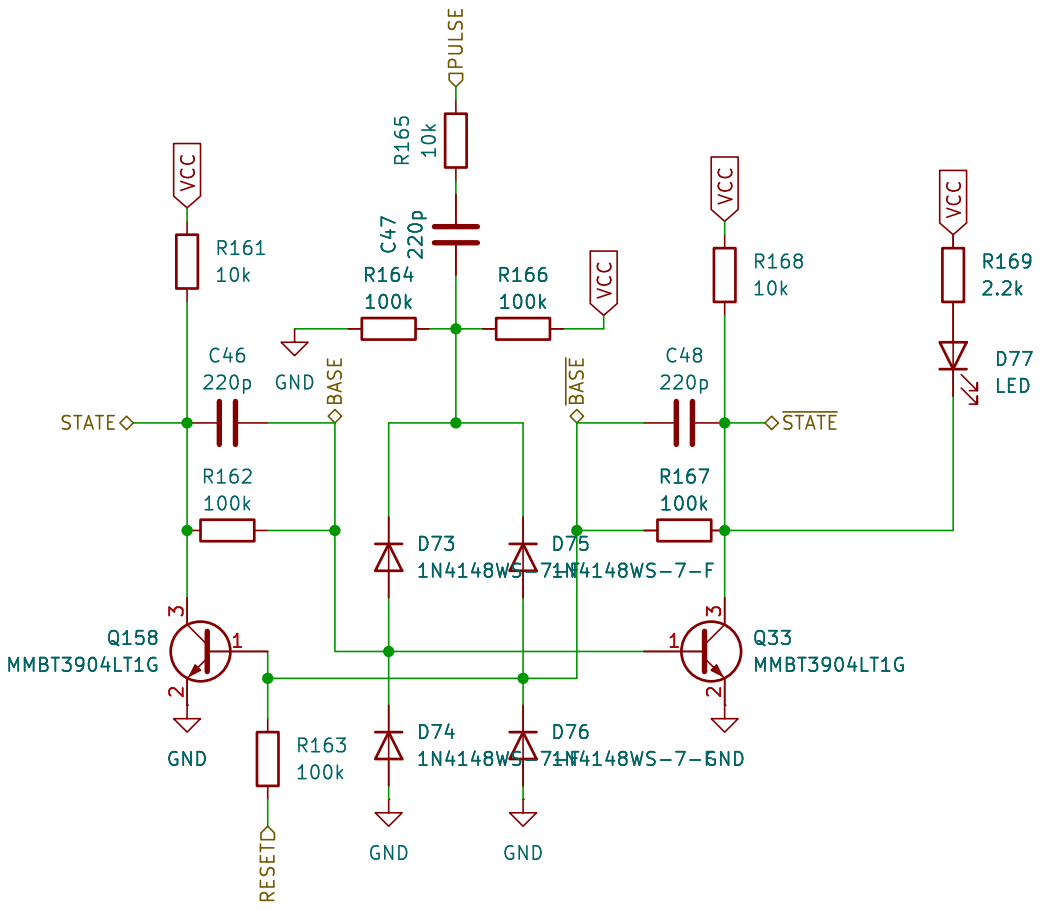
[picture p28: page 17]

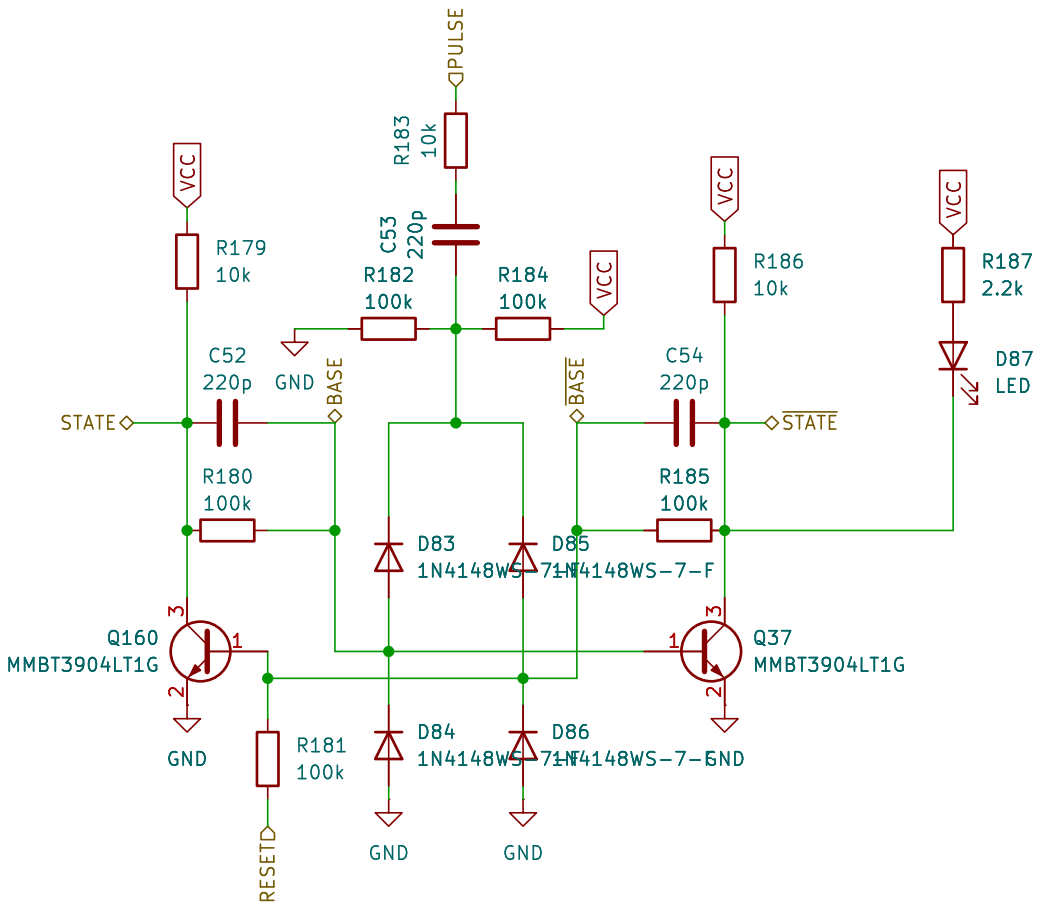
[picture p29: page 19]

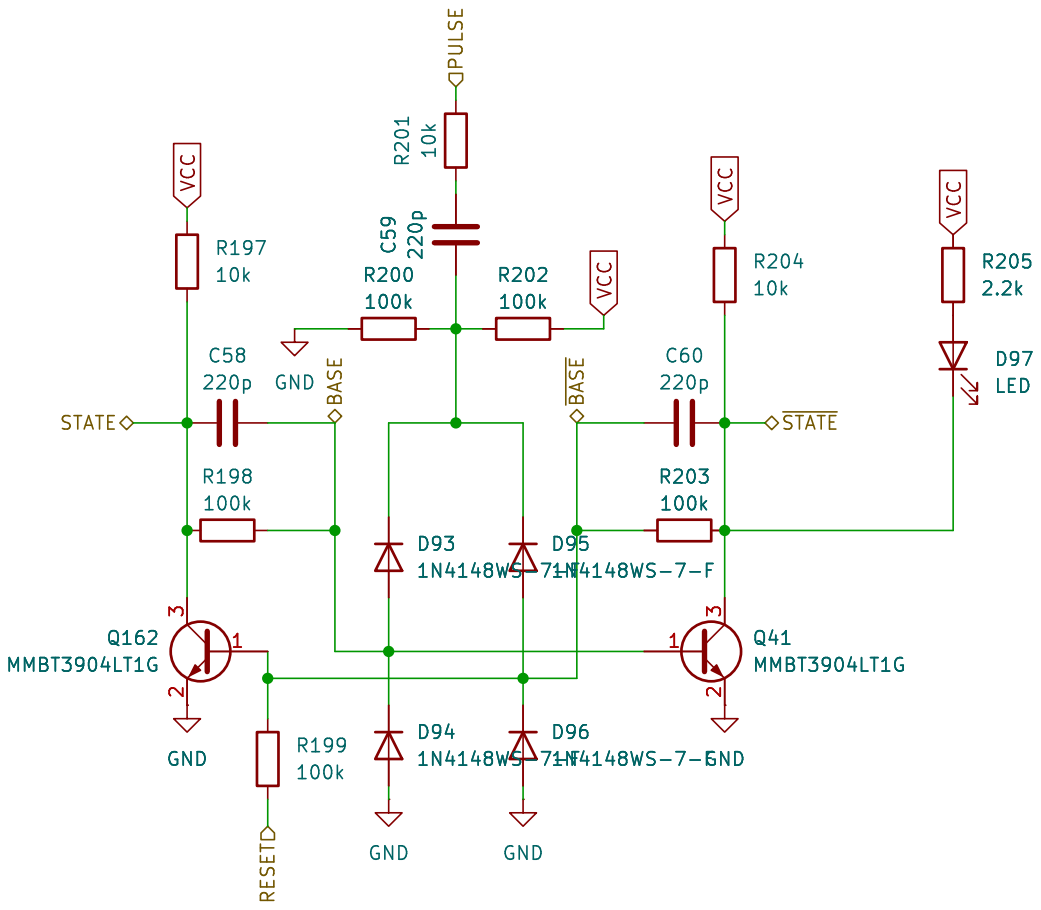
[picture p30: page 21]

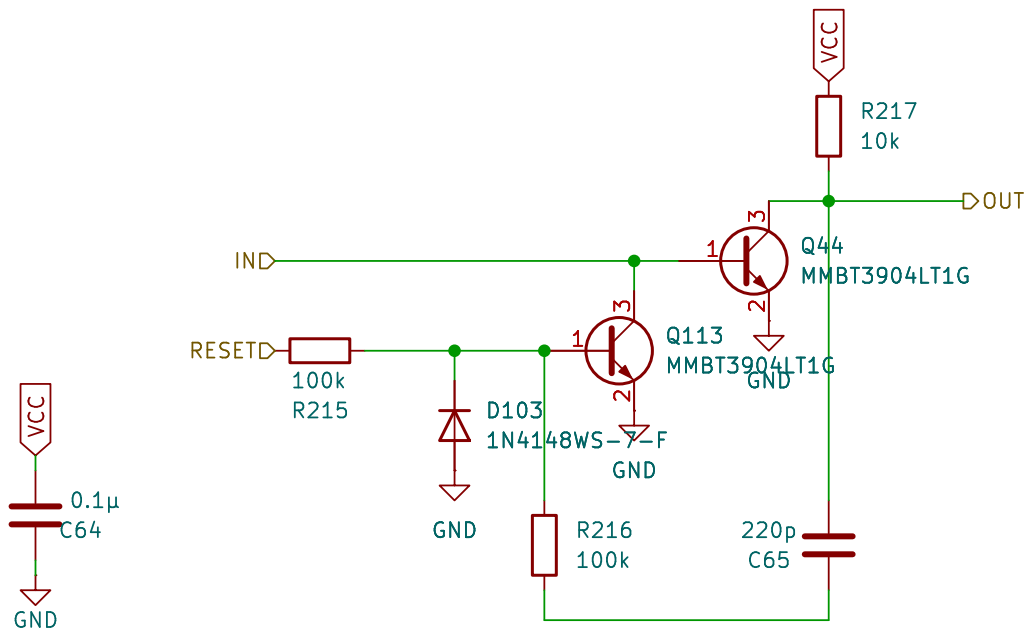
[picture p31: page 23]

Id: 23/52 Title: File: counter_reset.kicad_sch Sheet: /seconds/counter_reset1/ GND

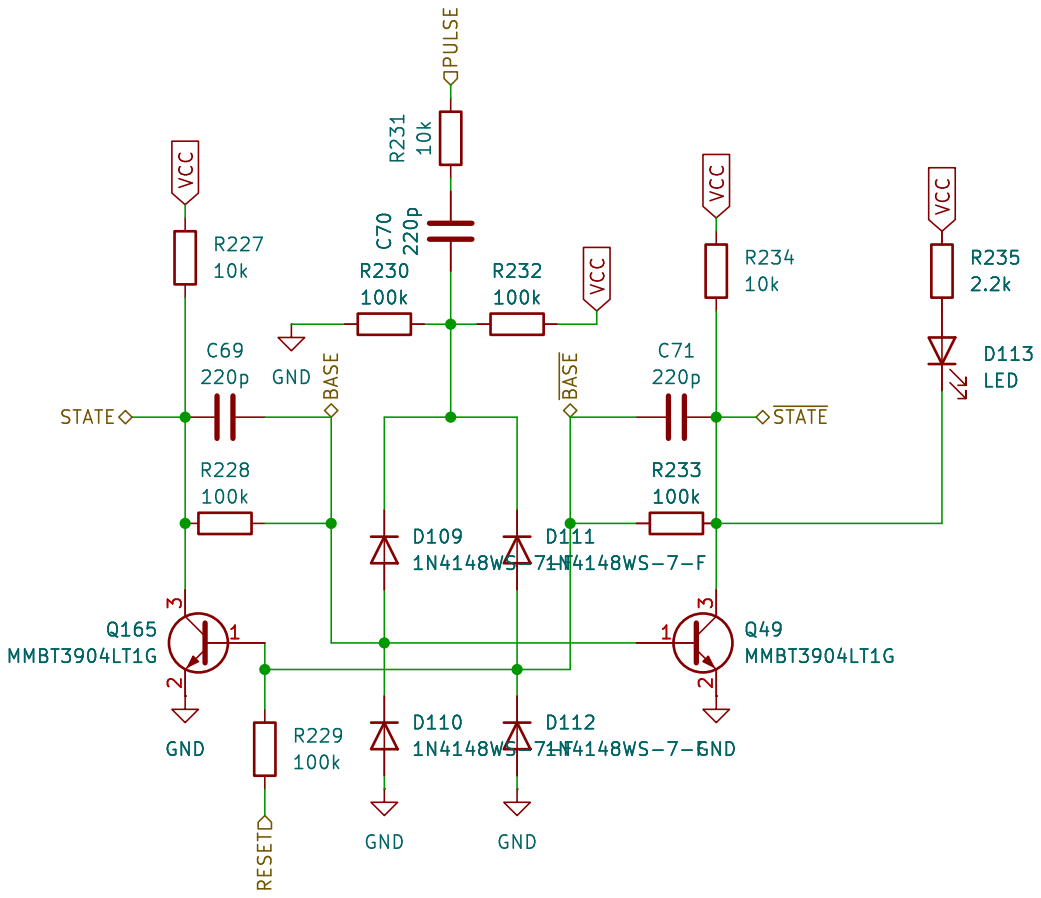
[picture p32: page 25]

Id: 27/52 Title: File: counter_pnp.kicad_sch Sheet: /multiplexer/counter_pnp1/ GND


File: psu.kicad_sch Sheet: /psu/ 1

Id: 29/52 Title: Power suply


Id: 30/52 Title: Multiplexer File: multiplexer.kicad_sch Sheet: /multiplexer/ PULSE



Id: 31/52 Title: Decoder File: decoder.kicad_sch Sheet: /decoder/


Id: 34/52 Title: File: counter_reset.kicad_sch Sheet: /seconds/counter_reset/ GND








Id: 51/52 Title: File: counter_pnp.kicad_sch Sheet: /multiplexer/counter_pnp/ GND

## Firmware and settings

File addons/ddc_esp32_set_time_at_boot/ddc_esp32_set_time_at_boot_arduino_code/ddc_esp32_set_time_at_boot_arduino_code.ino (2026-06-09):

/*
  Arduino IDE recommended settings for lower power:

  Tools -> CPU Frequency -> 80MHz
  Tools -> Flash Frequency -> 40MHz

*/




#include <WiFi.h>
#include <WebServer.h>
#include <Preferences.h>
#include "time.h"

WebServer server(80);
Preferences preferences;

const char* AP_SSID = "ESP32-WiFi-Setup";
const char* NTP_SERVER = "pool.ntp.org";

// ===== RESET BUTTON =====
// Button between GPIO 33 and GND
// Must be held LOW for 3 seconds during boot
const int RESET_WIFI_PIN = 33;

// ===== CLOCK PINS =====
// GPIO 32 is used as BOTH:
// - analog input to sense clock state
// - output HIGH to start clock exactly at second 00
const int CLOCK_ENABLE_SENSE_PIN = 32;

const int CLOCK_HOUR_PIN   = 26;
const int CLOCK_MINUTE_PIN = 27;

// 0V means reset/off
// ~1.4V means running
// Anything below this is treated as reset/off
const int CLOCK_RESET_THRESHOLD_MV = 700;

// Pulse timing
const int PULSE_HIGH_MS = 50;
const int PULSE_LOW_MS  = 20;

// true  = 24-hour clock: 0-23 hour pulses
// false = 12-hour clock: 1-12 hour pulses
const bool USE_24_HOUR_CLOCK = true;

// Clock setup state
bool clockSetupRunning = false;
bool clockSetRequested = false;
bool timeIsKnown = false;
bool portalMode = false;

unsigned long lastClockCheckTime = 0;
unsigned long lastClockSetupTime = 0;

const unsigned long CLOCK_CHECK_INTERVAL_MS = 250;
const unsigned long CLOCK_RECHECK_DELAY_MS = 5000;

String savedTimezone = "UTC0";

String htmlPage() {
  return R"rawliteral(
<!DOCTYPE html>
<html>
<head>
  <meta charset="UTF-8">
  <title>WiFi Config</title>
  <style>
    body {
      font-family: Arial, sans-serif;
      background: #f7f9fc;
      padding: 40px;
      display: flex;
      flex-direction: column;
      align-items: center;
      color: #333;
    }

    h2 {
      color: #2c3e50;
    }

    form {
      background: white;
      padding: 20px 25px;
      border-radius: 10px;
      box-shadow: 0 2px 8px rgba(0,0,0,0.1);
      width: 100%;
      max-width: 340px;
    }

    label {
      display: block;
      margin-bottom: 6px;
      font-weight: bold;
    }

    input, select {
      width: 100%;
      padding: 10px;
      margin-bottom: 15px;
      border: 1.5px solid #ccc;
      border-radius: 5px;
      box-sizing: border-box;
      font-size: 14px;
    }

    input[type="submit"] {
      background: #3498db;
      color: white;
      border: none;
      cursor: pointer;
      font-weight: bold;
    }

    input[type="submit"]:hover {
      background: #2980b9;
    }
  </style>
</head>
<body>

  <h2>Configure WiFi</h2>

  <form id="wifiForm">
    <label for="ssid">SSID:</label>
    <input type="text" id="ssid" required>

    <label for="password">Password:</label>
    <input type="password" id="password">

    <label for="timezone">Time Zone:</label>
    <select id="timezone" required></select>

    <input type="submit" value="Submit">
  </form>

  <script>
    const timezoneSelect = document.getElementById("timezone");

    for (let offset = -12; offset <= 14; offset++) {
      const option = document.createElement("option");

      const sign = offset >= 0 ? "+" : "-";
      const absOffset = Math.abs(offset);

      option.textContent = "UTC" + sign + String(absOffset).padStart(2, "0") + ":00";

      // POSIX timezone format is reversed:
      // UTC+01:00 becomes UTC-1
      // UTC-05:00 becomes UTC5
      option.value = offset === 0 ? "UTC0" : "UTC" + String(-offset);

      if (offset === 0) {
        option.selected = true;
      }

      timezoneSelect.appendChild(option);
    }

    document.getElementById("wifiForm").addEventListener("submit", function(e) {
      e.preventDefault();

      fetch("/set", {
        method: "POST",
        headers: { "Content-Type": "application/x-www-form-urlencoded" },
        body: "ssid=" + encodeURIComponent(document.getElementById("ssid").value) +
              "&password=" + encodeURIComponent(document.getElementById("password").value) +
              "&timezone=" + encodeURIComponent(document.getElementById("timezone").value)
      })
      .then(response => response.text())
      .then(text => alert(text))
      .catch(err => alert("Error: " + err));
    });
  </script>

</body>
</html>
)rawliteral";
}

void printDivider() {
  Serial.println();
  Serial.println("========================================");
}

void floatClockEnableSensePin() {
  pinMode(CLOCK_ENABLE_SENSE_PIN, INPUT);
  Serial.println("[CLOCK] Enable/sense pin is INPUT / high impedance");
}

void driveClockEnableHigh() {
  pinMode(CLOCK_ENABLE_SENSE_PIN, OUTPUT);
  digitalWrite(CLOCK_ENABLE_SENSE_PIN, HIGH);
  Serial.println("[CLOCK] Enable/sense pin driven HIGH");
}

int readClockSenseMillivolts() {
  floatClockEnableSensePin();
  delay(2);

#if defined(ESP32)
  return analogReadMilliVolts(CLOCK_ENABLE_SENSE_PIN);
#else
  int raw = analogRead(CLOCK_ENABLE_SENSE_PIN);
  return map(raw, 0, 4095, 0, 3300);
#endif
}

bool isClockInResetState() {
  int mv = readClockSenseMillivolts();

  Serial.print("[CLOCK] Sense voltage: ");
  Serial.print(mv);
  Serial.println(" mV");

  return mv < CLOCK_RESET_THRESHOLD_MV;
}

void setupClockPins() {
  pinMode(CLOCK_HOUR_PIN, OUTPUT);
  pinMode(CLOCK_MINUTE_PIN, OUTPUT);

  digitalWrite(CLOCK_HOUR_PIN, LOW);
  digitalWrite(CLOCK_MINUTE_PIN, LOW);

  analogReadResolution(12);
  analogSetPinAttenuation(CLOCK_ENABLE_SENSE_PIN, ADC_11db);

  floatClockEnableSensePin();

  Serial.println("[CLOCK] Clock pins initialized");
  Serial.print("[CLOCK] Enable/sense pin: GPIO ");
  Serial.println(CLOCK_ENABLE_SENSE_PIN);
  Serial.print("[CLOCK] Hour pin: GPIO ");
  Serial.println(CLOCK_HOUR_PIN);
  Serial.print("[CLOCK] Minute pin: GPIO ");
  Serial.println(CLOCK_MINUTE_PIN);
  Serial.println("[CLOCK] Separate off-state sensing wire removed");
}

void pulsePin(int pin, int count, const char* label) {
  Serial.print("[CLOCK] Pulsing ");
  Serial.print(label);
  Serial.print(" pin ");
  Serial.print(count);
  Serial.println(" times");

  for (int i = 0; i < count; i++) {
    digitalWrite(pin, HIGH);
    delay(PULSE_HIGH_MS);

    digitalWrite(pin, LOW);
    delay(PULSE_LOW_MS);

    Serial.print("[CLOCK] ");
    Serial.print(label);
    Serial.print(" pulse ");
    Serial.print(i + 1);
    Serial.print("/");
    Serial.println(count);
  }
}

bool internalTimeLooksValid() {
  time_t now = time(nullptr);
  return now > 1700000000;  // Roughly after 2023
}

void printCurrentLocalTime(const char* prefix) {
  time_t now = time(nullptr);

  struct tm timeInfo;
  localtime_r(&now, &timeInfo);

  char timeString[64];
  strftime(timeString, sizeof(timeString), "%A, %d %B %Y %H:%M:%S", &timeInfo);

  Serial.print(prefix);
  Serial.println(timeString);
}

void waitForWiFiForever(String ssid, String password) {
  printDivider();
  Serial.println("[WIFI] Waiting for WiFi connection forever...");
  Serial.print("[WIFI] SSID: ");
  Serial.println(ssid);

  WiFi.mode(WIFI_STA);
  WiFi.setAutoReconnect(true);
  WiFi.persistent(false);

  while (WiFi.status() != WL_CONNECTED) {
    Serial.println("[WIFI] Starting connection attempt...");
    WiFi.disconnect(false);
    delay(500);
    WiFi.begin(ssid.c_str(), password.c_str());

    unsigned long startTime = millis();

    while (WiFi.status() != WL_CONNECTED && millis() - startTime < 15000) {
      Serial.print(".");
      delay(500);
    }

    Serial.println();

    if (WiFi.status() == WL_CONNECTED) {
      Serial.println("[WIFI] Connected successfully!");
      Serial.print("[WIFI] IP address: ");
      Serial.println(WiFi.localIP());
      Serial.print("[WIFI] Gateway: ");
      Serial.println(WiFi.gatewayIP());
      Serial.print("[WIFI] Signal strength RSSI: ");
      Serial.print(WiFi.RSSI());
      Serial.println(" dBm");
      return;
    }

    Serial.println("[WIFI] Connection failed. Retrying...");
    delay(2000);
  }
}

void syncTimeUntilSuccess(String ssid, String password, String timezone) {
  printDivider();
  Serial.println("[TIME] Will retry NTP until valid time is received");

  configTzTime(timezone.c_str(), NTP_SERVER);

  while (!internalTimeLooksValid()) {
    if (WiFi.status() != WL_CONNECTED) {
      Serial.println("[TIME] WiFi is not connected while waiting for NTP");
      waitForWiFiForever(ssid, password);
      configTzTime(timezone.c_str(), NTP_SERVER);
    }

    Serial.print("[TIME] Waiting for NTP sync");

    struct tm timeInfo;
    bool gotTime = false;

    for (int attempts = 0; attempts < 20; attempts++) {
      if (getLocalTime(&timeInfo, 500)) {
        gotTime = true;
        break;
      }

      Serial.print(".");

      if (WiFi.status() != WL_CONNECTED) {
        Serial.println();
        Serial.println("[TIME] WiFi disconnected during NTP sync");
        break;
      }
    }

    Serial.println();

    if (gotTime && internalTimeLooksValid()) {
      timeIsKnown = true;
      Serial.println("[TIME] Time synchronized successfully");
      printCurrentLocalTime("[TIME] Current local time: ");
      return;
    }

    Serial.println("[TIME] NTP sync failed. Retrying...");
    delay(2000);
  }

  timeIsKnown = true;
  Serial.println("[TIME] Internal time already looks valid");
  printCurrentLocalTime("[TIME] Current local time: ");
}

void disableWiFiAfterTimeSync() {
  printDivider();
  Serial.println("[WIFI] Time is known, disabling WiFi now");
  Serial.println("[WIFI] ESP32 will continue using internal clock");

  WiFi.disconnect(true);
  WiFi.mode(WIFI_OFF);

  delay(200);

  Serial.println("[WIFI] WiFi disabled");
}

void waitForZeroSecondAndStartClock() {
  Serial.println("[CLOCK] Waiting for real time second 00...");
  Serial.println("[CLOCK] Enable/sense pin will be driven HIGH immediately at second 00");

  int lastSecond = -1;

  while (true) {
    time_t now = time(nullptr);

    struct tm timeInfo;
    localtime_r(&now, &timeInfo);

    if (timeInfo.tm_sec != lastSecond) {
      Serial.print("[CLOCK] Current second: ");
      Serial.println(timeInfo.tm_sec);
      lastSecond = timeInfo.tm_sec;
    }

    if (timeInfo.tm_sec == 0) {
      driveClockEnableHigh();

      char timeString[64];
      strftime(timeString, sizeof(timeString), "%A, %d %B %Y %H:%M:%S", &timeInfo);

      Serial.print("[CLOCK] Clock start pin driven HIGH at exact sync point: ");
      Serial.println(timeString);

      break;
    }

    delay(1);
  }
}

void setClockAfterZeroSecond() {
  if (clockSetupRunning) {
    Serial.println("[CLOCK] Clock setup is already running, ignoring request");
    return;
  }

  if (!timeIsKnown) {
    Serial.println("[CLOCK] Clock setup requested but time is not known yet");
    return;
  }

  clockSetupRunning = true;

  printDivider();
  Serial.println("[CLOCK] Clock setup requested");
  printCurrentLocalTime("[CLOCK] Internal time now: ");

  floatClockEnableSensePin();
  Serial.println("[CLOCK] Enable/sense pin floating before synchronization");

  waitForZeroSecondAndStartClock();

  time_t now = time(nullptr);

  struct tm timeInfo;
  localtime_r(&now, &timeInfo);

  int hour = timeInfo.tm_hour;
  int minute = timeInfo.tm_min;

  int hourPulses;

  if (USE_24_HOUR_CLOCK) {
    hourPulses = hour;
  } else {
    hourPulses = hour % 12;

    if (hourPulses == 0) {
      hourPulses = 12;
    }
  }

  int minutePulses = minute;

  char setTimeString[64];
  strftime(setTimeString, sizeof(setTimeString), "%A, %d %B %Y %H:%M:%S", &timeInfo);

  Serial.print("[CLOCK] Setting clock to: ");
  Serial.println(setTimeString);

  Serial.print("[CLOCK] Hour pulses needed: ");
  Serial.println(hourPulses);

  Serial.print("[CLOCK] Minute pulses needed: ");
  Serial.println(minutePulses);

  pulsePin(CLOCK_HOUR_PIN, hourPulses, "HOUR");
  pulsePin(CLOCK_MINUTE_PIN, minutePulses, "MINUTE");

  Serial.println("[CLOCK] Clock setup finished");

  floatClockEnableSensePin();
  Serial.println("[CLOCK] Enable/sense pin returned to INPUT mode for voltage sensing");

  lastClockSetupTime = millis();
  clockSetupRunning = false;
}

void startPortal() {
  printDivider();
  Serial.println("[PORTAL] Starting WiFi configuration portal...");

  portalMode = true;

  WiFi.mode(WIFI_AP);
  WiFi.softAP(AP_SSID);

  IPAddress apIP = WiFi.softAPIP();

  Serial.println("[PORTAL] Access Point started");
  Serial.print("[PORTAL] AP SSID: ");
  Serial.println(AP_SSID);
  Serial.println("[PORTAL] AP password: none / open network");
  Serial.print("[PORTAL] AP IP address: ");
  Serial.println(apIP);
  Serial.println("[PORTAL] Connect to this WiFi and open the IP above");

  server.on("/", []() {
    Serial.println("[HTTP] GET / - Sending WiFi config page");
    server.send(200, "text/html", htmlPage());
  });

  server.on("/set", HTTP_POST, []() {
    Serial.println("[HTTP] POST /set - Received setup data");

    String ssid = server.arg("ssid");
    String password = server.arg("password");
    String timezone = server.arg("timezone");

    Serial.print("[WIFI] Received SSID: ");
    Serial.println(ssid);

    Serial.print("[WIFI] Password length: ");
    Serial.println(password.length());

    Serial.print("[TIME] Received timezone: ");
    Serial.println(timezone);

    if (ssid == "") {
      Serial.println("[ERROR] Empty SSID received");
      server.send(400, "text/plain", "SSID is required");
      return;
    }

    if (timezone == "") {
      Serial.println("[ERROR] Empty timezone received");
      server.send(400, "text/plain", "Timezone is required");
      return;
    }

    Serial.println("[NVS] Saving settings to flash...");

    preferences.begin("wifi", false);
    preferences.putString("ssid", ssid);
    preferences.putString("password", password);
    preferences.putString("timezone", timezone);
    preferences.end();

    Serial.println("[NVS] Settings saved successfully");
    Serial.println("[SYSTEM] Restarting ESP32 in 1 second...");

    server.send(200, "text/plain", "Saved. ESP32 will restart and connect.");

    delay(1000);
    ESP.restart();
  });

  server.onNotFound([]() {
    Serial.print("[HTTP] Redirecting unknown page: ");
    Serial.println(server.uri());

    server.sendHeader("Location", "/", true);
    server.send(302, "text/plain", "");
  });

  server.begin();

  Serial.println("[HTTP] Web server started on port 80");
}

void checkWiFiResetButton() {
  pinMode(RESET_WIFI_PIN, INPUT_PULLUP);

  Serial.print("[RESET] WiFi reset pin: GPIO ");
  Serial.println(RESET_WIFI_PIN);
  Serial.println("[RESET] Hold button LOW for 3 seconds during boot to clear saved WiFi settings");

  delay(100);

  Serial.print("[RESET] Raw reset pin state: ");
  Serial.println(digitalRead(RESET_WIFI_PIN) == LOW ? "LOW" : "HIGH");

  if (digitalRead(RESET_WIFI_PIN) == HIGH) {
    Serial.println("[RESET] Reset button not pressed");
    return;
  }

  Serial.println("[RESET] Reset pin is LOW, checking if it stays LOW for 3 seconds...");

  unsigned long startTime = millis();

  while (millis() - startTime < 3000) {
    if (digitalRead(RESET_WIFI_PIN) == HIGH) {
      Serial.println("[RESET] Reset button released before 3 seconds");
      Serial.println("[RESET] WiFi settings will NOT be cleared");
      return;
    }

    delay(50);
  }

  printDivider();
  Serial.println("[RESET] Reset button held LOW for 3 seconds");
  Serial.println("[RESET] Clearing saved WiFi credentials and timezone...");

  preferences.begin("wifi", false);
  preferences.clear();
  preferences.end();

  Serial.println("[RESET] Saved settings cleared");
  Serial.println("[RESET] Starting configuration portal");

  startPortal();

  while (true) {
    server.handleClient();
    delay(2);
  }
}

void connectSavedWiFiAndGetTime() {
  printDivider();
  Serial.println("[BOOT] Reading saved settings...");

  preferences.begin("wifi", true);
  String ssid = preferences.getString("ssid", "");
  String password = preferences.getString("password", "");
  savedTimezone = preferences.getString("timezone", "UTC0");
  preferences.end();

  if (ssid == "") {
    Serial.println("[BOOT] No saved SSID found");
    Serial.println("[BOOT] Starting configuration portal");
    startPortal();
    return;
  }

  Serial.print("[BOOT] Saved SSID found: ");
  Serial.println(ssid);

  Serial.print("[BOOT] Saved password length: ");
  Serial.println(password.length());

  Serial.print("[BOOT] Saved timezone: ");
  Serial.println(savedTimezone);

  waitForWiFiForever(ssid, password);
  syncTimeUntilSuccess(ssid, password, savedTimezone);
  disableWiFiAfterTimeSync();

  if (isClockInResetState()) {
    Serial.println("[CLOCK] Clock is in reset/off state after time sync");
    clockSetRequested = true;
  } else {
    Serial.println("[CLOCK] Clock appears to already be running after time sync");
  }
}

void checkClockSensePin() {
  if (!timeIsKnown) {
    return;
  }

  if (clockSetupRunning) {
    return;
  }

  if (millis() - lastClockCheckTime < CLOCK_CHECK_INTERVAL_MS) {
    return;
  }

  lastClockCheckTime = millis();

  if (millis() - lastClockSetupTime < CLOCK_RECHECK_DELAY_MS) {
    return;
  }

  if (isClockInResetState()) {
    Serial.println("[CLOCK] Clock reset/off voltage detected");
    clockSetRequested = true;
  }
}

void handleClockSetRequest() {
  if (!clockSetRequested) {
    return;
  }

  clockSetRequested = false;

  if (!timeIsKnown) {
    Serial.println("[CLOCK] Clock setup requested but time is not known");
    return;
  }

  setClockAfterZeroSecond();
}










void setup() {

  btStop();
  
  Serial.begin(115200);
  delay(1000);

  printDivider();
  Serial.println("[SYSTEM] ESP32 booting...");
  Serial.println("[SYSTEM] Serial Monitor baud rate: 115200");

  setupClockPins();

  checkWiFiResetButton();

  connectSavedWiFiAndGetTime();
}

void loop() {

  if (portalMode) {
    server.handleClient();
    return;
  }

  checkClockSensePin();
  handleClockSetRequest();

  delay(1000);

}

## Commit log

2025-07-19 Switch to Cayman theme
2025-07-19 Added some images schematics and license
2025-07-20 Added power_suply picture
2025-07-22 Added pcb picture and improved description.
2025-07-23 MOved pcb picture to correct spot
2025-07-23 Added main schematic
2026-05-25 Change index.md for new version
    Updated various sections for clarity and accuracy, including component specifications and voltage ratings.
2026-05-26 Added simple boot clock set esp32 addon
2026-05-26 Revise README for clarity on setup and troubleshooting
    Updated README.md to clarify power supply options, GPIO usage, and troubleshooting steps.
2026-05-27 Update README to clarify ESP32 clock setting process
    Clarified the functionality of the ESP32 add-on regarding time setting.
2026-05-31 Remove manufacturer names for specific components
    Removed manufacturer names for Screw Terminal and Button Switch.
2026-06-05 Enhance description for ESP32 WiFi Clock Setter
    Expanded description of the ESP32 WiFi Clock Setter addon.
2026-06-05 Update overview.md with pin numbering details
    Added information about pin numbering for headers.
2026-06-05 Correct pin numbering description in overview.md
2026-06-05 Added 3D file of clock
    [DDC.3mf]
2026-06-05 Include 3D model links in overview.md
    Added links to view and download the 3D model of the clock case.
2026-06-06 Update description of multiplexing signal in pictures.md
    Corrected terminology regarding wire properties in the LTspice capture description.
2026-06-07 Fix typos and update section title in pictures.md
    Corrected typos in the description of power supply ripple and updated section title.
2026-06-07 Update PCB description for shielding details
    Clarified PCB shielding description to specify GND copper pour on both sides.
2026-06-07 Remove PCB description from index.md
    Removed a descriptive line about the Discrete Digital Clock PCB.
2026-06-07 Added power usage and moved some stuff
2026-06-09 Remove setLowPowerRuntimeStart function
    Removed low-power runtime start function and its logging.
2026-06-18 Add PWM brightness control section to pictures.md
    Added PWM brightness control section with images and descriptions.
